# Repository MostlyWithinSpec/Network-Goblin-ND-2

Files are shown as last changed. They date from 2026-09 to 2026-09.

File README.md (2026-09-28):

# Network Goblin ND-2

**A Linux-powered handheld network multitool with real cable diagnostics.**

ND-2 is the bigger sibling of the [ND-1](#the-network-goblin-family) pocket cable tester. It's a custom carrier board for the Raspberry Pi Compute Module 5 with:

- a **dedicated test port** that can find opens, shorts and distance-to-fault on each pair (PHY-based TDR),
- a second gigabit port for uplink, capture and inline tapping,
- a touchscreen, battery power, 2x USB-A and HDMI out,
- a normal Linux distro underneath, so tcpdump, Wireshark, iperf3, nmap and friends just work.

Everything here, hardware and software, is open source under the MIT license.

> **Status: early hardware.** The first board, the **TDR proof dongle**, is at the fab. The full ND-2 carrier is still at the spec stage. Nothing here has been tested on real hardware yet.

---

## What's in this repo

| Path | What it is |
|---|---|
| [`docs/spec.md`](docs/spec.md) | Full ND-2 hardware spec (draft): architecture, part choices, power, BOM, risks |
| [`docs/roadmap.md`](docs/roadmap.md) | Where the project is going and in what order |
| [`docs/bring-up.md`](docs/bring-up.md) | Step-by-step first power-on and test plan for the TDR dongle |
| [`docs/ordering-jlcpcb.md`](docs/ordering-jlcpcb.md) | Exact JLCPCB settings used to order the dongle, and how to keep the cost down |
| [`hardware/tdr-dongle/`](hardware/tdr-dongle/) | **Rev A TDR proof dongle**: KiCad project, fab files, BOM, pick-and-place |
| [`hardware/nd2-carrier/`](hardware/nd2-carrier/) | The full CM5 carrier board (not started yet) |
| [`software/cabletest/`](software/cabletest/) | `nd2-cabletest`: a friendly wrapper around the Linux cable-test tools |

## The TDR proof dongle (Rev A)

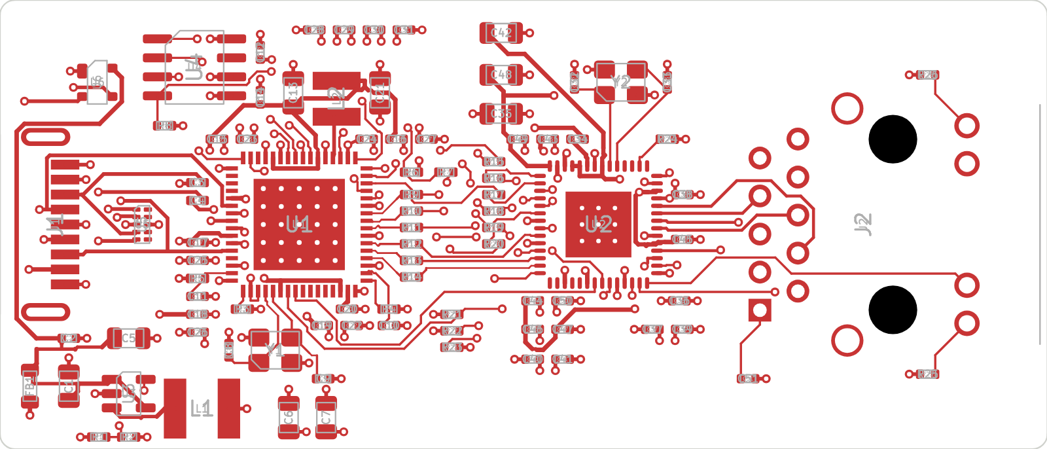
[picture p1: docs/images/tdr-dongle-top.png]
TDR dongle, top copper


A 70 x 30 mm USB 3 to gigabit Ethernet dongle that is **just the ND-2 test-port circuit**:

- **Microchip LAN7801**: USB 3 to RGMII MAC (`lan78xx` driver, mainline Linux)
- **Marvell 88E1512**: gigabit PHY with Virtual Cable Tester / TDR (`marvell` PHY driver, mainline Linux)
- **HanRun HR911130C**: 1G RJ45 magjack with LEDs
- 4-layer, 1.6 mm, all SMD parts on the top side, assembled by JLCPCB

It exists to prove that `ethtool --cable-test` works on this chip combo before building the full carrier. If it works, it's also useful by itself: **plug it into any Pi 5 or Linux laptop and you have a TDR cable tester.**

See [`hardware/tdr-dongle/README.md`](hardware/tdr-dongle/README.md) for the design details and fab files.

## Quick try (once you have a dongle)

```bash
# On a Pi 5 or any Linux machine with ethtool 5.8+ and a recent kernel
lsusb | grep 0424:7801             # the LAN7801 should show up
ip link                            # find the new interface, e.g. eth1
sudo ethtool --cable-test eth1     # per-pair OK / open / short + fault distance

# or the friendlier wrapper from this repo
sudo python3 software/cabletest/nd2-cabletest.py eth1
```

Unplug the far end of the cable first. TDR results are unreliable while there's an active link partner.

## The Network Goblin family

| Device | What it is |
|---|---|
| **ND-1** | Cheap, instant-on pocket cable tester. ESP32 + LAN8742A, 3.5" LCD. |
| **ND-2** | This repo. Linux handheld multitool on CM5, with a TDR test port. |
| **TDR dongle** | The ND-2 test port on its own, as a USB 3 dongle for any Linux box. |

## Contributing

Issues and pull requests are welcome, whether it's hardware review, bring-up results or software. See [CONTRIBUTING.md](CONTRIBUTING.md). Hardware bring-up reports on real boards are especially useful right now.

## License

[MIT](LICENSE), covering both hardware and software. Build it, fork it, sell it; a credit back to the project is appreciated.

**Not certified:** ND-2 isn't FCC/CE certified and isn't a TIA/ISO cable certifier. It tells you whether a cable is healthy enough, not whether it passes a formal certification test.

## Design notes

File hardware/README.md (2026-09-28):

# Hardware

| Board | Status | Folder |
|---|---|---|
| TDR proof dongle, Rev A | Ordered (JLCPCB, Sept 2026) | [`tdr-dongle/`](tdr-dongle/) |
| ND-2 CM5 carrier | Spec only | [`nd2-carrier/`](nd2-carrier/) |

All boards use **KiCad 10**. Each board folder is a self-contained KiCad project with its own symbol and footprint libraries.

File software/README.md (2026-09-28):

# ND-2 software

| Folder | What it is | Status |
|---|---|---|
| [`cabletest/`](cabletest/) | `nd2-cabletest.py`: per-pair cable test summary using `ethtool --cable-test` | Written, waiting for hardware |
| *(planned)* `eeprom/` | LAN7801 EEPROM image + script (MAC address, RGMII config) | After bring-up |
| *(planned)* `gui/` | Touch UI for the ND-2 handheld (LVGL on Linux DRM) | Stage 4 |

## nd2-cabletest

```bash
sudo apt install ethtool
sudo python3 software/cabletest/nd2-cabletest.py eth1
```

Example output (illustrative):

```
Cable test on eth1

Pair  Pins            Result                    Fault at
A     1-2 (orange)    OPEN                      12.4 m
B     3-6 (green)     OPEN                      12.6 m
C     4-5 (blue)      OPEN                      12.3 m
D     7-8 (brown)     OPEN                      12.5 m

All pairs open at about 12.5 m: that's probably the cable length (far end unplugged), not a fault.
```

It works with any Linux NIC whose PHY driver supports cable test, not just the ND-2 dongle.

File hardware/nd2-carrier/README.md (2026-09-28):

# ND-2 CM5 carrier board

Not started. It will begin once the TDR dongle proves the LAN7801 + 88E1512 test-port circuit ([roadmap](../../docs/roadmap.md)).

The design target is in [`docs/spec.md`](../../docs/spec.md): CM5 carrier, TDR test port (copied from the dongle), CM5 native uplink port, USB 3 hub + 2x USB-A, M.2 2230, DSI touchscreen, HDMI, USB-C PD input, 2S Li-ion with BQ25798 charger and fuel gauge.

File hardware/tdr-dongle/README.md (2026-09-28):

# ND-2 TDR Proof Dongle — Rev A

Top copper

A small USB 3 → Gigabit Ethernet dongle that is just the ND-2 test-port circuit:
**Microchip LAN7801** (USB 3 to RGMII MAC) + **Marvell 88E1512** (GbE PHY with VCT/TDR) + HanRun 1G magjack.
Plug it into a Pi 5 / CM5 IO board and prove `ethtool --cable-test` / `--cable-test-tdr` before building the CM5 carrier.

**Status:** ERC and DRC clean, schematic/PCB parity clean, ordered from JLCPCB in Sept 2026. **Not yet tested on real hardware.** Bring-up plan: [docs/bring-up.md](../../docs/bring-up.md).

## Files

| File | What it is |
| --- | --- |
| `tdr-dongle.kicad_sch` | Schematic (KiCad 10, one A2 sheet, label-based wiring) |
| `ND2.kicad_sym` + `sym-lib-table` | Project symbols: `ND2:LAN7801`, `ND2:88E1512`, `ND2:HR911130C` |
| `ND2.pretty` + `fp-lib-table` | Project footprints (from LCSC/EasyEDA, cleaned up — see below) |
| `bom_jlcpcb.csv` | Grouped BOM in JLCPCB format (Comment, Designator, Footprint, LCSC Part #) |
| `bom.csv` | One line per part with MPN + LCSC |
| `netlist_report.txt` | Every net and the pins on it |
| `tdr-dongle.kicad_pcb` | PCB: 70 x 30 mm, 4-layer |
| `tdr-dongle.kicad_pro` | KiCad project (design rules, net classes) |
| `tdr-dongle.net` | KiCad netlist export |
| `fab/` | Fabrication package: Gerber zip, JLC BOM + CPL, layer PDF, schematic PDF, STEP, renders |
| `scripts/` | Python scripts that generated the schematic and PCB (see [scripts/README.md](scripts/README.md)) |

## Parts (LCSC, checked 2026-09-25)

| Ref | Part | LCSC | Footprint | Notes |
| --- | --- | --- | --- | --- |
| U1 | LAN7801-I/9JX | C633491 | ND2:LAN7801_QFN-64-1EP_9x9mm_P0.5mm_EP6.1mm | Only ~13 in stock at LCSC |
| U2 | 88E1512-A0-NNP2C000 | C845579 | ND2:88E1512_QFN-56-1EP_8x8mm_P0.5mm_EP4.4mm | Only ~13 in stock at LCSC |
| U3 | TLV62569DBVR | C141836 | SOT-23-5 | 3V3 buck |
| U4 | 93AA66/SN | C615340 | SOIC-8 | ORG pin (6) tied to GND = 512 x 8 |
| U5 | TPD4EUSB30DQAR | C90627 | USON-10 | USB 3 ESD |
| U6 | PRTR5V0U2X,215 | C12333 | SOT-143 | USB 2 ESD |
| J1 | HC-USB3.0-C26 (USB 3 Type-A plug, SMD) | C7501854 | ND2:USB3_A_Plug_HongCheng_HC-USB3.0-C26 | Flash-drive style plug at the board edge |
| J2 | HanRun HR911130C (1G magjack, 2 LEDs) | C50933 | ND2:RJ45_HanRun_HR911130C_Horizontal | Replaces the Pulse JK0654219NL (0 stock) |
| Y1, Y2 | X322525MOB4SI 25 MHz, CL 12 pF | C9006 | Crystal_SMD_3225-4Pin | Load caps changed to 15 pF |
| L1 | SMNR4020-2.2UH (3.4 A) | C135262 | ND2:L_4.0x4.0mm_SMNR4020 | Buck inductor |
| L2 | SMNR3015-3R3MT (1.32 A) | C135239 | ND2:L_3.0x3.0mm_SMNR3015 | LAN7801 1V2 switcher |
| FB1 | MPZ2012S601AT000 (600 Ω, 2 A) | C21519 | L_0805 | VBUS filter |
| Caps | 100 nF C1525 · 1 µF C52923 · 220 nF C16772 · 15 pF C1548 (0402) · 10 µF C15850 · 22 µF C45783 (0805) | | | |
| Resistors (0402, UNI-ROYAL) | 22R C25092 · 330R C25104 · 0R C17168 · 1.5k C25867 · 2k C4109 · 4.99k C25903 · 10k C25744 · 12k C25752 · 100k C25741 · 453k C27009 | | | |

## Changes from the first draft

- **Magjack → HanRun HR911130C.** The Pulse part had no stock. The HR911130C has one **common** center tap (pin 1 → one 100 nF to GND) and an internal Bob-Smith termination on pin 10 (tied to GND). LEDs: 11/12 green (anode/cathode), 14/13 yellow (anode/cathode).
- **EEPROM → 93AA66/SN** (the x8-only 93AA66A wasn't stocked in SOIC). ORG pin tied low selects 512 x 8.
- **Crystals → 12 pF load** (YXC, 70k in stock); load caps now 15 pF.
- **Real footprints** for U1, U2, J1, J2, L1, L2, taken from LCSC/EasyEDA and fixed up:
  - LAN7801 pads resized to Microchip's recommended land pattern (0.30 × 0.85 mm pads, 6.1 mm exposed pad), plus 5 × 5 thermal vias (0.33 mm) and a split paste stencil.
  - 88E1512 exposed pad 4.4 mm (datasheet D2/E2 = 4.37 mm), 3 × 3 thermal vias numbered to the pad, split paste.
  - HR911130C / USB plug pads renumbered to match the symbols; the RJ45 plastic posts made non-plated.

## Known issues and Rev B ideas

1. **Stock on U1 / U2** — about 13 of each at LCSC right now. Enough for a few prototypes; for more, JLCPCB global sourcing or Mouser/Digi-Key.
2. **J1 plug** hangs over the board edge and was left off the JLC assembly (hand-soldered). Rev B: USB-C receptacle + cable.
3. RGMII series resistors (22 Ω) are a starting value; tune after the first boards.
4. Optional: low-capacitance TVS on the MDI pairs, test points on RGMII/MDIO.

## Bring-up plan

1. Power only: check +5V, +3V3, LAN_1V2, LAN_2V5, PHY_1V8, PHY_1V0.
2. Plug into a Pi 5: `lsusb` should show 0424:7801. Program the EEPROM with MAC + HW_CFG (hybrid RGMII delay, CLK125_EN).
3. `dmesg` should show lan78xx attaching the Marvell 88E1510-family PHY at address 0.
4. Link test: clean 1 Gb/s link, iperf3, watch for CRC errors (wrong RGMII delay).
5. TDR: `ethtool --cable-test ethX` and `ethtool --cable-test-tdr ethX` on known cables (open, short, known lengths).

## PCB and fab package (Rev A)

- Board: 70 x 30 mm, 4-layer 1.6 mm (JLC04161H-7628). F.Cu signals, In1 = GND plane, In2 = +3V3 plane, B.Cu signals.
- Rules: 0.1 mm min track (Freerouting necks to ~0.11 at the QFN pins), 0.127 mm clearance, 0.6/0.3 mm vias.
- Routing: plane fan-out by script (scripts/fanout.py), the rest by Freerouting 2.4.1, and 2 nets fixed by hand (scripts/fix_last2.py).
- DRC: 0 errors, 0 warnings, 0 unconnected, schematic parity clean (KiCad 10.0.5).

`fab/` holds:
- `tdr-dongle_gerbers_JLC.zip`: Gerbers + Excellon drills. Upload this to JLCPCB and pick 4 layers, 1.6 mm, JLC04161H-7628.
- `tdr-dongle_BOM_JLC.csv`: the BOM (R7 is DNP and left out).
- `tdr-dongle_CPL_JLC.csv`: pick and place (89 parts, all top side, origin at the board's lower-left corner).
- `tdr-dongle_layers.pdf`, `tdr-dongle_schematic.pdf`, `tdr-dongle.step`, and top/bottom renders for review.

Caveats:
- USB3 and MDI pairs were autorouted. They are **not** length-matched or impedance-controlled. That is fine for a proof dongle but not final.
- Check part rotations in JLC's CPL preview, especially J1, J2, U1, U2 and the crystals.
- LAN7801 and 88E1512 LCSC stock was low (~13 each) when checked.

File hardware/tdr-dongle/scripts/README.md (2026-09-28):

# Generation scripts

The Rev A schematic and PCB were generated by script, then checked in KiCad. These scripts are kept for reference and for building later revisions the same way.

> **Heads-up:** most scripts have a placeholder Windows project path hard-coded (`C:\path\to\ND2\tdr-dongle`) and expect KiCad 10's bundled Python (`C:\Program Files\KiCad\10.0\bin\python.exe`). Change the `P = ...` line at the top before running them.

| Script | Step | What it does |
|---|---|---|
| `gen_dongle.py` | 1 | Writes `tdr-dongle.kicad_sch` (label-based schematic). **Overwrites the schematic.** |
| `fix_courtyards.py`, `fix_usb_edge.py`, `fix_rj45_silk.py` | 2 | One-off clean-ups of the EasyEDA-imported footprints in `ND2.pretty` |
| `build_pcb.py` | 3 | Builds `tdr-dongle.kicad_pcb` from `tdr-dongle.net`: outline, stackup, rules, net classes, placement, planes. **Overwrites the PCB.** |
| `fanout.py` | 4 | Adds locked stub + via fan-outs from every GND / +3V3 pad to the inner planes |
| `route_start.py` / `route_finish.py` | 5 | Exports Specctra DSN, runs Freerouting 2.4.1 (needs Java 25), imports the SES |
| `fix_last2.py` | 6 | Hand-routes the two connections Freerouting left open (LAN_SW, C24 +3V3) |
| `drc_brief.py`, `drc_summary.py` | check | Runs `kicad-cli pcb drc` with schematic parity and prints a summary |
| `render_layers.py`, `render_zoom.py` | check | SVG exports for visual review |
| `export_fab.py` | 7 | Writes the fab package (Gerbers + drill zip, JLC CPL, BOM, PDFs, STEP) |
| `export_dsn.py`, `run_seq.py` | helpers | DSN export on its own; run several scripts one after another |

Because the PCB was routed by hand after these scripts ran, **re-running `build_pcb.py` will throw away the routing.** Edit the board in KiCad from here on.

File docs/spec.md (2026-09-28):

# Network Goblin ND-2 — Hardware Spec (Draft)

*Draft, 2026-09-25. Mirrors the working spec doc; this copy lives with the hardware so changes can go through pull requests.*

## 1. Overview

ND-2 is the Linux-powered member of the Network Goblin family: a handheld network multitool built as a custom carrier board for the Raspberry Pi Compute Module 5. ND-1 stays the cheap, instant-on pocket cable tester (ESP32 + LAN8742A). ND-2 is the one you bring when you need to capture, measure, tap and poke at a live network.

**Goals**

- Cable diagnostics on a dedicated test port: per-pair open/short detection, distance to fault and cable length (PHY TDR).
- Two gigabit Ethernet ports: one test port with TDR, one general-purpose port.
- Packet capture (tcpdump / Wireshark / tshark), iperf3 throughput testing, inline tap (bridge), port-mirror target.
- Security-oriented tooling (nmap, scapy, Kismet-type tools, etc.) on a standard Linux distro.
- Handheld and battery powered, with a small capacitive touchscreen running a custom GUI.
- 2x USB-A, one HDMI output for occasional desk use.
- Fully open source (hardware + software), kept at a sensible cost so the community can build it.

**Non-goals**

- TIA/ISO cable **certification** (NEXT, return loss, insertion loss up to 250–500 MHz). PHY-based TDR can't do that, and it's not the point. ND-2 checks that a line is in spec *enough*, or mostly in spec.
- A fail-open passive tap in Rev A (inline tap is an active Linux bridge; see Risks).
- Wiremap / split-pair detection without a remote unit (possible future accessory).

## 2. System architecture

```mermaid
flowchart LR
  subgraph TEST["Test path (TDR)"]
    RJT["Test port RJ45<br/>magjack"] --- PHY["Marvell 88E1512<br/>GbE PHY + VCT/TDR"]
    PHY -- "RGMII + MDIO" --- LAN["LAN7801<br/>USB 3 to RGMII MAC"]
  end
  LAN -- "USB 3" --- CM5["Raspberry Pi CM5<br/>BCM2712 · BCM54210PE PHY"]
  CM5 -- "MDI (on-module PHY)" --- RJU["Uplink RJ45"]
  CM5 -- "USB 3" --- HUB["USB 3 hub"] --- USBA["2x USB-A"]
  CM5 -- "PCIe x1" --- M2["M.2 2230<br/>NVMe or Wi-Fi"]
  CM5 -- "DSI + I2C" --- LCD["Touchscreen"]
  CM5 -- "HDMI0" --- HDMI["HDMI out"]
  USBC["USB-C in<br/>PD 9-15 V"] --> CHG["PD sink + BQ25798<br/>2S charger"]
  CHG --- BAT["2S Li-ion + fuel gauge"]
  CHG -- "VSYS" --> BUCK["5 V / 5 A buck<br/>+ 3.3 V rail"] --> CM5
```
*ND-2 system architecture (CM5 carrier). The top group is the TDR test path.*

The CM5's two USB 3 ports do the heavy lifting: one feeds a LAN7801 + Marvell 88E1512 to make the TDR-capable test port, the other feeds a small hub for the two USB-A ports. The CM5's own gigabit PHY becomes the uplink port, which leaves the single PCIe lane free for an M.2 slot.

| Interface | Source on CM5 | Used for |
|---|---|---|
| eth0 (native) | On-module BCM54210PE PHY | Uplink / capture / mirror target / iperf |
| eth1 (test) | USB 3 port 0 → LAN7801 → Marvell 88E1512 | Cable diagnostics, link tests, second leg of inline tap |
| USB-A x2 | USB 3 port 1 → 4-port USB 3 hub | Adapters, Wi-Fi dongles, storage, keyboard |
| M.2 2230 (M- or E-key, TBD) | PCIe Gen2/3 x1 | NVMe for captures or a monitor-mode Wi-Fi card |
| Touchscreen | MIPI DSI (4-lane) + I2C | Primary UI |
| HDMI | HDMI0 | Occasional desktop use |
| USB-C | Power input (+ optional USB 2 gadget/console) | Charging, data link to a laptop |

## 3. Compute module

**Choice: Raspberry Pi Compute Module 5.** From the [CM5 datasheet](https://datasheets.raspberrypi.com/cm5/cm5-datasheet.pdf):

- 2x USB 3.0 (5 Gb/s, usable at the same time) + 1x USB 2.0
- 1x PCIe Gen 2 x1 (Gen 3 possible but unsupported)
- On-module Broadcom BCM54210PE gigabit PHY with IEEE 1588 PTP
- 2x HDMI 2.0, 2x 4-lane MIPI (DSI or CSI)
- 5 V input (4.75–5.25 V), up to 5 A budget with USB loads; ~0.4 A idle, ~0.9 A typical
- PWR_BUT (pin 92), PMIC_EN (pin 99), RTC VBAT (pin 76), Fan_PWM / Fan_Tacho (pins 19/16)

**Why not CM4:** the CM4 only has USB 2.0 (480 Mb/s). A USB-attached second NIC would be stuck well below gigabit, and the only way around that is the single PCIe lane, which is then gone for USB 3 or storage. PCIe NICs that work well on the Pi (Realtek RTL8111, Intel i210/i225) have no cable-test support in Linux. The CM5's native USB 3 removes the whole problem.

**Variants to support:**

| Variant | Notes |
|---|---|
| CM5 Lite (no eMMC), 2–4 GB | Cheapest build. Boots from microSD slot on the carrier (or NVMe if M.2 is M-key). Recommended community default. |
| CM5 with eMMC, 4–8 GB | Faster, more robust boot. Heavier Wireshark/Kismet use benefits from 4 GB+. |
| Wireless vs non-wireless | Either works. On-module Wi-Fi is fine for management; monitor-mode security work should use a USB or M.2 adapter anyway. Needs antenna keep-out (10 mm) or U.FL if the case is metal. |

The carrier keeps the standard 2x 100-pin Hirose DF40 footprint. A CM4 would physically fit but would lose USB 3 (so the test port and USB-A ports fall back to USB 2 speeds); treat that as unsupported rather than a design target.

## 4. Networking

### 4.1 Test port (eth1): LAN7801 + Marvell 88E1512

- **MAC bridge:** Microchip LAN7801, 64-pin SQFN. USB 3.0 SuperSpeed + USB 2.0 upstream to CM5 USB3 port 0 (0.1 µF AC-coupling caps on SS TX). Linux driver: `lan78xx` (mainline, used on the Pi 3B+ already). The LAN7801 stays no matter which PHY sits behind it; it's what turns USB 3 into an Ethernet MAC.
  - 25 MHz crystal; REFCLK_25 output can clock the PHY (saves a second crystal).
  - Internal 2.5 V LDO and 1.2 V switcher (needs 3.3 µH + 22 µF).
  - VDDVARIO = 3.3 V or 1.8 V for the RGMII bank; match the PHY's VDDO.
  - 3-wire 93C66-type EEPROM for MAC address and config, including the MAC-side RGMII clock delays (not optional with the Marvell PHY).
  - ~10 Ω series resistors on RGMII lines, 1.5 k pull-up on MDIO.
- **PHY: Marvell 88E1512** (56-pin QFN 8x8, LCSC C845579, ~$11 at qty 1 vs ~$3.70 for the KSZ9131RNX). RGMII to the LAN7801, MDI to the RJ45. Linux driver: `marvell`, which supports both `--cable-test` (per-pair status + fault distance) and `--cable-test-tdr` (raw amplitude vs. distance for a real TDR trace).
  - Runs from a single 3.3 V supply using its internal switching regulator; VDDO selectable 1.8/2.5/3.3 V.
  - RGMII delays must be added in exactly one place. Plan: the LAN7801 adds TX/RX clock delays (set in its EEPROM) and the PHY runs plain RGMII. Others have paired non-Microchip PHYs with the LAN7801 this way. Fallback: have the PHY insert the delays instead (register-configured; the Marvell driver does this from the interface mode) through a small driver/overlay tweak.
  - Reference clock from LAN7801 REFCLK_25; keep a 25 MHz crystal footprint as a DNP backup.
  - Docs: Marvell's full register manual is behind their customer portal, but a public product datasheet exists and the mainline Linux driver already implements the VCT/TDR sequences, so nothing ND-2 needs is locked away.
  - Fallback part: KSZ9131RNX (Microchip's own LAN7801 pairing, simpler bring-up, no raw TDR). Not footprint-compatible, so the choice is made per board revision.
- **Connector:** RJ45 magjack with integrated magnetics and LEDs (same family as ND-1, e.g. HanRun HR911130 class 1G part). TVS array on MDI pairs (e.g. low-capacitance 4-line array), shield to chassis ground through RC.

### 4.2 Uplink port (eth0): CM5 native

- CM5's BCM54210PE MDI pairs route straight to a second 1G magjack. LEDs from CM5 Ethernet_nLED pins.
- This is the "fast" port: on-SoC MAC, PTP-capable, lowest latency. Use it for iperf, captures and as the mirror target.

### 4.3 Operating modes (software)

| Mode | Ports | Notes |
|---|---|---|
| Cable test | eth1 | Link down, run TDR, show per-pair result + distance |
| Link / port check | eth1 or eth0 | Negotiated speed/duplex, PoE present (future), LLDP/CDP neighbor, VLAN, DHCP, gateway ping, DNS |
| Throughput | eth0 (or both) | iperf3 client/server; port-to-port loopback test through a switch |
| Capture | eth0 / eth1 | tcpdump/tshark to NVMe or USB; live summary on screen; export pcap |
| Port-mirror target | eth0 | Promiscuous capture from a switch SPAN port |
| Inline tap | eth0 + eth1 bridged | Linux bridge; capture on br0. Active tap: link breaks if ND-2 powers off |
| Security tools | any | nmap, scapy, arp-scan, responder-type tools, Kismet with USB/M.2 Wi-Fi |

Throughput note: USB 3 gives the LAN7801 plenty of headroom for 1 Gb/s line rate, but bridging both ports at full duplex line rate will be CPU-bound. Expect it to be fine for typical tap/capture use; benchmark in bring-up.

## 5. Cable diagnostics

**What the 88E1512 Virtual Cable Tester (VCT) gives you** through the standard Linux ethtool netlink cable-test API (driver already in mainline, no NDA needed):

- Per pair (A–D): OK, open, short within pair, short to another pair
- Distance to the fault; Marvell specs fault location to within about 1 m
- **Raw TDR trace:** `--cable-test-tdr` returns reflection amplitude vs. distance for each pair, with configurable start/stop/step. The GUI can plot a real TDR view that shows bad connectors, kinks and mismatched patch cords, not just open/short.
- **Cable length:** leave the far end unplugged; each pair shows an open at the cable's end, and that distance is the length. The GUI should prompt for this ("Unplug far end for length").
- **With link up at 1 Gb/s:** the PHY's DSP also estimates cable length and reports pair swaps, polarity and pair skew in vendor registers. ethtool doesn't expose these, but a small MDIO helper can read them for the link-check screen.

**How the test runs:** the driver drops the link while testing. Results are cleanest with the far end unplugged or its device powered off; the GUI should warn when a link partner is detected.

**What it can't do**

- Certification-grade measurements (NEXT, return loss, insertion loss vs. frequency)
- Split-pair detection and full wiremap without a remote identifier at the far end
- Length through ethtool on a cable plugged into a live switch (pairs read OK with no distance; use the DSP length estimate instead)

**Filling the gaps cheaply**

- **Link qualification:** force 1000BASE-T, run a 30 s iperf3 or packet-generator test against a known endpoint, read PHY error counters and link flaps. "Passes gigabit cleanly" is the practical in-spec check.
- **Wiremap remote (future accessory):** a tiny passive or MCU-based terminator with distinct resistor/diode signatures per pair, like the remotes that come with cheap wiremap testers. Could be shared with ND-1.

**Software path:** `ethtool --cable-test eth1` for the pass/fail summary and `ethtool --cable-test-tdr eth1` for the trace. The GUI calls the same netlink API directly (pyroute2 or libmnl).

## 6. USB, storage and expansion

- **USB 3 hub:** VIA VL817 (4-port USB 3.0 hub, widely stocked, cheap) on CM5 USB3 port 1. Two downstream ports go to USB-A; the spare two are left for a future internal module (e.g. an internal Wi-Fi or SDR daughterboard).
- **2x USB-A:** vertical or right-angle USB 3 receptacles. Each behind a current-limited load switch (~1 A each, e.g. TPS2553-class) so a shorted dongle can't brown out the CM5. ESD protection on D+/D− and SS pairs.
- **USB-C:** power input (see Power). Optionally route CM5's USB 2.0 port here too for gadget mode (serial console / USB-Ethernet to a laptop) with a mux or simple jumper; verify CM5 device-mode support on this port during bring-up.
- **microSD:** required for CM5 Lite (SDIO on the CM5 connector). Push-push socket, card-detect to a GPIO.
- **M.2 slot (PCIe x1):** recommend **M-key 2230/2242 for NVMe** as the default. Captures go to fast storage, and the Pi 5 ecosystem supports NVMe boot. Monitor-mode Wi-Fi is better served by USB adapters, which have more mature driver support. Include a PCIe CLKREQ/reset per CM5 IO board reference, 3.3 V at 2–3 A from its own buck.
- **HDMI:** one micro- or mini-HDMI (full-size if the case allows) on HDMI0, with an HDMI ESD/level companion (TPD12S016-class) handling DDC level shifting, HPD and the 5 V current limit.
- **Fan header:** 2-pin or 4-pin to CM5 Fan_PWM/Fan_Tacho. A small blower is likely needed in an enclosed handheld during long captures.

## 7. Display, controls and indicators

**Display:** MIPI DSI touchscreen on one of the CM5's 4-lane MIPI ports, 22-pin 0.5 mm FPC (the CM-style DSI connector; 2-lane panels also fit). Touch controller on the I2C lines in the same cable, backlight/touch power from a separate 5 V / 3.3 V pin header.

| Option | Size / res | Why |
|---|---|---|
| Raspberry Pi Touch Display 2 (5") | 720x1280 | Official driver, zero bring-up work, easy for builders to buy |
| Waveshare 4.3" or 5" DSI LCD | 800x480 | Cheaper, smaller, Pi-compatible overlays exist |
| Bare DSI panel + custom FPC | 4–5" | Best fit for a handheld case later; more driver work |

Recommendation: design around the official 5" panel for Rev A (known-good), keep the connector generic so cheaper panels work.

**Controls**

- Power button to CM5 PWR_BUT (short press = on / clean shutdown, hold 5 s = force off)
- Hard power switch in the battery path for storage/shipping
- 3–4 GPIO buttons: Back, Home, and a dedicated **Test** button that runs a cable test on eth1 without touching the screen

**Indicators and extras**

- Charge status LED from the charger; one addressable RGB status LED (test pass/fail, capture running)
- Magjack LEDs on both ports
- RTC: rechargeable ML2032-type cell or supercap to CM5 VBAT so capture timestamps survive battery swaps
- Debug UART header (3-pin) and a Qwiic/STEMMA I2C connector for add-ons (e.g. a PoE detector board)

## 8. Power system

**Why 2S, not 1S:** peak system load is 15–20 W with USB devices attached. From a single 3.7 V cell that's 5+ A through a boost converter, which means hot inductors, big voltage droop and early brown-outs. A 2S pack (6.0–8.4 V) lets a simple buck make 5 V efficiently.

**Chain:** USB-C → PD sink → buck-boost charger with power path → VSYS (pack voltage) → 5 V / 5 A buck → CM5 + peripherals; a second buck from VSYS for 3.3 V (M.2, LAN7801, PHY).

| Block | Part (proposed) | Notes |
|---|---|---|
| PD sink | TI TPS25730 | Standalone, strap-configured (no firmware), integrated power switches, LCSC stocked. Request 9–15 V; falls back to 5 V on dumb chargers |
| Charger / power path | TI BQ25798 | I2C, 1–4 cell, 5 A buck-boost, 3.6–24 V input. Buck-boost means even a plain 5 V USB charger can charge the 2S pack. Runs the system from USB when plugged in |
| Battery | 2S1P Li-ion, 21700 or 18650 (with PCM) | 2x 21700 5000 mAh ≈ 36 Wh. Use a pack with built-in protection + balancing, or add a 2S protector/balancer (e.g. BQ29209-class) |
| Fuel gauge | TI BQ34Z100-G1 | Multi-cell gauge with real %-remaining; I2C to CM5. Low-battery interrupt triggers clean shutdown |
| 5 V rail | 5 V / 5–6 A sync buck (e.g. TPS56637-class, 4.5–28 V in) | Feeds CM5 (via its 5 V pins), USB hub, USB-A load switches, display |
| 3.3 V rail | 3 A sync buck from VSYS | M.2, LAN7801, 88E1512 (the CM5's own 3.3 V output is only ~600 mA total, not enough) |
| On/off | CM5 PWR_BUT + PMIC_EN, hard switch in pack line | Gauge/charger stays alive for charging while the system is off |

**Power budget (estimates, to confirm on the bench)**

| Load | Typical | Peak |
|---|---|---|
| CM5 (idle ~2 W, working ~4.5 W) | 4.5 W | 10 W |
| LAN7801 + 88E1512 at 1 Gb/s | 1.0 W | 1.5 W |
| 5" DSI display + backlight | 1.5 W | 2.0 W |
| USB hub | 0.5 W | 0.8 W |
| NVMe (idle / writing) | 0.5 W | 3.0 W |
| USB-A devices (e.g. Wi-Fi adapter) | 1.5 W | 9.0 W (2x 0.9 A) |
| **Total** | **~9.5 W** | **~26 W** |

The worst case assumes both USB-A ports at full current while the CPU and NVMe are maxed out, which is rare; firmware can cap USB-A current if needed. Expected runtime on a 36 Wh pack at ~9.5 W average with ~88% conversion efficiency: **roughly 3–3.5 hours** of active use.

## 9. Preliminary BOM (key parts)

Passives, ESD parts and connectors beyond the main ones are left out. Part numbers are starting points; check LCSC/JLC stock before locking the schematic.

| Function | Part | Qty | Package |
|---|---|---|---|
| Compute | Raspberry Pi CM5 (Lite 4 GB suggested default) | 1 | Module |
| CM connectors | Hirose DF40C-100DS-0.4V (carrier side) | 2 | 100-pin |
| USB3 → RGMII MAC | Microchip LAN7801 | 1 | 64-SQFN |
| TDR PHY | Marvell 88E1512-A0-NNP2C000 (fallback: KSZ9131RNX) | 1 | 56-QFN 8x8 |
| MAC config EEPROM | 93C66-type 3-wire (required: MAC + RGMII delay config) | 1 | SOT-23/SOIC |
| 25 MHz crystal | For LAN7801 (PHY clocked from REFCLK_25) | 1 | 3225 |
| RJ45 magjack, 1G, LEDs | HanRun HR911130-class | 2 | THT |
| USB 3 hub | VIA VL817 | 1 | QFN-76 |
| USB-A receptacles (USB 3) | Generic | 2 | THT |
| USB-A load switches | TPS2553-class | 2 | SOT-23-6 |
| HDMI companion | TPD12S016-class | 1 | QFN |
| micro/mini HDMI connector | Generic | 1 | SMD |
| M.2 M-key socket + standoff | Generic | 1 | SMD |
| microSD socket | Push-push | 1 | SMD |
| DSI FPC connector | 22-pin 0.5 mm | 1 | SMD |
| USB-C receptacle (16-pin) | Generic | 1 | SMD |
| PD sink | TI TPS25730 | 1 | QFN |
| Charger | TI BQ25798 | 1 | QFN-29 |
| Fuel gauge | TI BQ34Z100-G1 | 1 | TSSOP-14 |
| 5 V buck | TPS56637-class + inductor | 1 | SOT/QFN |
| 3.3 V buck | 3 A sync buck + inductor | 1 | SOT |
| RTC cell | ML2032 rechargeable + holder | 1 | THT/SMD |
| Battery | 2S 21700 pack with PCM + JST-XH balance lead | 1 | — |

## 10. Cost strategy for open-source adoption

The CM5 is the single most expensive part, so most savings come from letting builders pick their own module and leaving optional parts unpopulated.

- **The carrier doesn't include the module.** Builders choose any CM5: a Lite 2–4 GB for a budget build, eMMC/8 GB for heavy capture work. Document which features need which RAM size.
- **Optional-population zones:** M.2 slot, HDMI, hub ports 3–4, fan header and fuel gauge can be left off without breaking anything. Mark them DNP-friendly in the BOM.
- **Buy-don't-build for the screen and battery:** off-the-shelf DSI panel and a standard 2S pack keep the carrier simple and JLC-assemblable.
- **Keep all fine-pitch parts on one side** so JLCPCB standard assembly can do the whole board; hand-solder only THT (RJ45, USB-A, battery connector).
- **Public documentation first** (Microchip, TI, VIA). The one partial exception is the Marvell PHY: its full register manual is gated, but everything ND-2 uses is already in the open-source Linux driver, so forks aren't blocked.
- **Firmware reuse:** the ND-1 LVGL UI concepts can carry over. LVGL runs on Linux framebuffer/DRM, so screens, icons and the goblin style can be shared between ND-1 and ND-2.

## 11. Risks, open questions and bring-up plan

**Risks**

| Risk | Impact | Mitigation |
|---|---|---|
| lan78xx + external PHY RGMII delay setup | Test port doesn't link or has CRC errors | Set delays in one place (LAN7801 EEPROM), keep PHY-side delay as a fallback, prove it on a small LAN7801 + 88E1512 test board before the full carrier |
| TDR less reliable with a live link partner | Wrong or "unknown" results | GUI detects a link partner and asks the user to unplug the far end |
| High-speed routing (USB 3, PCIe, HDMI, DSI, MDI) | Signal integrity problems | 4- or 6-layer stackup with controlled impedance (90 Ω USB/PCIe, 100 Ω MIPI/HDMI/MDI); copy the CM5 IO board's routing rules |
| Thermal in a closed handheld | CPU throttling during capture | Fan header, CM5 heatsink contact to case, measure early |
| 2S pack safety and shipping | Fire risk, hard to ship kits | Only protected packs; builder sources battery locally |
| Active tap fails closed | Inline link drops if ND-2 dies | Document it; consider a relay-based bypass in Rev B |

**Open questions**

- Test port PHY: decided on Marvell 88E1512 (raw TDR trace); KSZ9131RNX is the fallback.
- M.2 as M-key (NVMe) or E-key (Wi-Fi)?
- Screen size and orientation: 5" portrait-native panel used in landscape, or a 4.3" 800x480?
- Include PoE detection on the test port (voltage + class sensing) in Rev A or as an add-on?
- Case form factor: handheld "brick" like ND-1 scaled up, or tablet-style?

**Bring-up plan**

1. **TDR proof board:** a small USB 3 dongle PCB with just the test-port circuit (LAN7801 + 88E1512 + EEPROM + magjack). Plug it into a CM5 IO board or a Pi 5, get the link stable at 1 Gb/s (RGMII delays), then confirm `ethtool --cable-test` and `--cable-test-tdr` on Raspberry Pi OS. Cheap to iterate, and the schematic drops straight into the carrier.
1. **Rev A carrier:** full feature set, generous test points, 0 Ω jumpers on every rail so each block can be powered up alone.
1. **Power-on order:** power chain alone (no CM5) → add CM5 + boot from SD → USB hub → LAN7801/PHY → display → M.2 → battery-only runtime test.
1. **Validate:** cable test against known-length cables with opens/shorts built in, iperf3 at line rate on both ports, bridged tap throughput, thermal soak, battery runtime.

## Sources

- [Raspberry Pi CM5 datasheet](https://datasheets.raspberrypi.com/cm5/cm5-datasheet.pdf)
- [Marvell PHY TDR amplitude graph patch](https://patches.linaro.org/project/netdev/patch/20200524152747.745893-5-andrew@lunn.ch/)
- [88E1512-A0-NNP2C000 at LCSC](https://www.lcsc.com/product-detail/C845579.html)
- [88E1512 overview (single 3.3 V supply, VCT, RGMII delay modes)](https://www.utmel.com/components/88e1512-a0-nnp2c000-energy-efficient-ethernet-transceiver-features-pinout-and-datasheet?id=1366)
- [KSZ9131RNX at LCSC](https://www.lcsc.com/product-detail/C1849397.html)
- [KSZ9031/KSZ9131 cable test kernel patch](https://patchwork.kernel.org/project/netdevbpf/patch/20220406185020.301197-1-marex@denx.de/)
- [LAN7801 schematic checklist](https://www.microchip.com/content/dam/mchp/documents/OTH/ProductDocuments/SupportingCollateral/SchematicChecklistLAN7801SQFNRevA.pdf)
- [EVB-LAN7801-KSZ9031 user guide](https://ww1.microchip.com/downloads/en/DeviceDoc/500002605A.pdf)
- [lan78xx LAN7801 external PHY discussion](https://patchew.org/linux/20240611094233.865234-1-rengarajan.s@microchip.com/)
- [LAN7801 with a non-Microchip PHY, delays set in EEPROM](https://lkml.iu.edu/2602.2/00468.html)
- [TI BQ25798 datasheet](https://www.ti.com/lit/ds/symlink/bq25798.pdf)
- [TI TPS25730](https://www.ti.com/product/TPS25730)

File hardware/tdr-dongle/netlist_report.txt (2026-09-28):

ND-2 TDR dongle - generated net list (net: ref.pin(name) ...)

+3V3           L1.2(2)  C6.1()  C7.1()  R1.1()  U1.29(VBUS_DET)  U1.33(DUPLEX)  U1.50(VDD33A)  U1.64(VDD33_REG_IN)  U1.21(VDD_SW_IN)  U1.3(VDDVARIO)  U1.7(VDDVARIO)  U1.11(VDDVARIO)  U1.18(VDDVARIO)  U1.27(VDDVARIO)  U1.48(VDDVARIO)  U1.51(VDDVARIO)  R5.1()  U4.8(VCC)  C12.1()  R8.2()  C21.1()  C22.1()  C23.1()  C24.1()  C25.1()  C26.1()  C27.1()  C28.1()  C29.1()  C30.1()  C31.1()  R21.1()  R22.1()  U2.20(AVDD33)  U2.25(AVDD33)  U2.36(REG_IN)  U2.11(VDDO)  U2.49(VDDO)  U2.52(VDDO)  C35.1()  C36.1()  C37.1()  C38.1()  C39.1()  C40.1()  C41.1()  R25.1()  R26.1()
+5V            FB1.2()  C1.1()  C2.1()  U6.4(VCC)  U3.1(EN)  U3.4(VIN)  C5.1()
BUCK_FB        U3.5(FB)  R1.2()  R2.1()
BUCK_SW        U3.3(SW)  L1.1(1)
EE_CLK         U1.26(EECLK/GPIO3)  U4.2(SCLK)
EE_CS          U1.23(EECS/GPIO0)  U4.1(CS)
EE_DI          U1.25(EEDO/GPIO2)  U4.3(DI)
EE_DO          U1.24(EEDI/GPIO1)  U4.4(DO)  R8.1()
GND            J1.4(GND)  J1.7(DRAIN)  J1.SH(SHIELD)  C1.2()  C2.2()  U5.3(GND)  U5.8(GND)  U6.1(GND)  U3.2(GND)  C5.2()  C6.2()  C7.2()  R2.2()  U1.46(TEST)  U1.65(VSS(EP))  Y1.2(G)  Y1.4(G)  C8.2()  C9.2()  R3.2()  R4.2()  C10.2()  C11.2()  R6.2()  U4.5(GND)  U4.6(ORG)  C12.2()  C13.2()  C14.2()  C15.2()  C16.2()  C17.2()  C18.2()  C19.2()  C20.2()  C21.2()  C22.2()  C23.2()  C24.2()  C25.2()  C26.2()  C27.2()  C28.2()  C29.2()  C30.2()  C31.2()  R23.2()  U2.15(CONFIG)  U2.10(VDDO_SEL)  U2.57(VSS(EP))  Y2.2(G)  Y2.4(G)  C32.2()  C33.2()  R24.2()  C35.2()  C36.2()  C37.2()  C38.2()  C39.2()  C40.2()  C41.2()  C42.2()  C43.2()  C44.2()  C45.2()  C46.2()  C47.2()  C48.2()  C49.2()  C50.2()  J2.10(CHS_GND)  J2.SH(SHIELD)  C51.2()
LAN_1V2        U1.22(VDD12_SW_FB)  U1.28(VDD12CORE)  U1.54(VDD12CORE)  U1.37(VDD12A)  U1.42(VDD12A)  U1.62(VDD12A)  L2.2(2)  C13.1()  C14.1()  C15.1()  C16.1()  C17.1()  C18.1()  C19.1()
LAN_2V5        U1.63(VDD25_REG_OUT)  C20.1()
LAN_CLK125     U1.19(CLK125)  R6.1()  R7.1()
LAN_REF_FILT   U1.2(REF_FILT)  C10.1()
LAN_REF_REXT   U1.1(REF_REXT)  R4.1()
LAN_RESET_N    U1.47(RESET_N/PME_CLEAR)  R5.2()  C11.1()
LAN_SW         U1.20(VDD12_SW_OUT)  L2.1(1)
LAN_TXC        U1.10(TXC)  R9.1()
LAN_TXD0       U1.8(TXD0)  R11.1()
LAN_TXD1       U1.6(TXD1)  R12.1()
LAN_TXD2       U1.5(TXD2)  R13.1()
LAN_TXD3       U1.4(TXD3)  R14.1()
LAN_TX_CTL     U1.9(TX_CTL)  R10.1()
LAN_USB3_TXN   C4.1()  U1.41(USB3_TXDM)
LAN_USB3_TXP   C3.1()  U1.40(USB3_TXDP)
LAN_USBRBIAS   U1.49(USBRBIAS)  R3.1()
LAN_XI         U1.52(XI)  Y1.1(1)  C8.1()
LAN_XO         U1.53(XO)  Y1.3(3)  C9.1()
LED_A0         J2.11(LED_G+)  R25.2()
LED_A1         J2.14(LED_Y+)  R26.2()
MDC            U1.56(MDC)  U2.7(MDC)
MDI0_N         U2.27(MDIN[0])  J2.3(MDI0-)
MDI0_P         U2.28(MDIP[0])  J2.2(MDI0+)
MDI1_N         U2.23(MDIN[1])  J2.7(MDI1-)
MDI1_P         U2.24(MDIP[1])  J2.4(MDI1+)
MDI2_N         U2.21(MDIN[2])  J2.6(MDI2-)
MDI2_P         U2.22(MDIP[2])  J2.5(MDI2+)
MDI3_N         U2.17(MDIN[3])  J2.9(MDI3-)
MDI3_P         U2.18(MDIP[3])  J2.8(MDI3+)
MDIO           U1.55(MDIO)  R21.2()  U2.8(MDIO)
MDI_CT         J2.1(CT)  C51.1()
PHY_1V0        U2.40(DVDD_OUT)  U2.6(DVDD)  U2.42(DVDD)  C48.1()  C49.1()  C50.1()
PHY_1V8        U2.39(AVDD18_OUT)  U2.3(AVDD18)  U2.19(AVDD18)  U2.26(AVDD18)  U2.38(AVDD18)  U2.35(AVDDC18)  C42.1()  C43.1()  C44.1()  C45.1()  C46.1()  C47.1()
PHY_CLK125     R7.2()  U2.9(CLK125)
PHY_INT_N      U1.31(PHY_INT_N)  R22.2()  U2.12(LED[2]/INTn)
PHY_LED0       U2.14(LED[0])  J2.12(LED_G-)
PHY_LED1       U2.13(LED[1])  J2.13(LED_Y-)
PHY_REGCAP1    U2.37(REGCAP1)  C34.1()
PHY_REGCAP2    U2.41(REGCAP2)  C34.2()
PHY_RESET_N    U1.32(PHY_RESET_N)  R23.1()  U2.16(RESETn)
PHY_RSET       U2.30(RSET)  R24.1()
PHY_RXC        R15.1()  U2.46(RX_CLK)
PHY_RXD0       R17.1()  U2.44(RXD[0])
PHY_RXD1       R18.1()  U2.45(RXD[1])
PHY_RXD2       R19.1()  U2.47(RXD[2])
PHY_RXD3       R20.1()  U2.48(RXD[3])
PHY_RX_CTL     R16.1()  U2.43(RX_CTRL)
PHY_XI         U2.34(XTAL_IN)  Y2.1(1)  C32.1()
PHY_XO         U2.33(XTAL_OUT)  Y2.3(3)  C33.1()
RGMII_RXC      U1.12(RXC)  R15.2()
RGMII_RXD0     U1.14(RXD0)  R17.2()
RGMII_RXD1     U1.15(RXD1)  R18.2()
RGMII_RXD2     U1.16(RXD2)  R19.2()
RGMII_RXD3     U1.17(RXD3)  R20.2()
RGMII_RX_CTL   U1.13(RX_CTL)  R16.2()
RGMII_TXC      R9.2()  U2.53(TX_CLK)
RGMII_TXD0     R11.2()  U2.50(TXD[0])
RGMII_TXD1     R12.2()  U2.51(TXD[1])
RGMII_TXD2     R13.2()  U2.54(TXD[2])
RGMII_TXD3     R14.2()  U2.55(TXD[3])
RGMII_TX_CTL   R10.2()  U2.56(TX_CTRL)
USB_DM         J1.2(D-)  U6.3(I/O2)  U1.39(USB2_DM)
USB_DP         J1.3(D+)  U6.2(I/O1)  U1.38(USB2_DP)
USB_SSRX_N     J1.5(SSRX-)  U5.5(D2-)  C4.2()
USB_SSRX_P     J1.6(SSRX+)  U5.4(D2+)  C3.2()
USB_SSTX_N     J1.8(SSTX-)  U5.2(D1-)  U1.44(USB3_RXDM)
USB_SSTX_P     J1.9(SSTX+)  U5.1(D1+)  U1.43(USB3_RXDP)
VBUS           J1.1(VBUS)  FB1.1()

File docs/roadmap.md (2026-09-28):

# ND-2 roadmap

The plan is to prove the risky part first (the TDR test port), then build outward.

## Stage 1: TDR proof dongle, Rev A *(in progress)*

LAN7801 + 88E1512 + magjack on a small 4-layer USB 3 dongle.

- [x] Schematic (ERC clean), LCSC parts, footprints
- [x] PCB layout and routing (DRC clean, schematic parity clean)
- [x] Fab package (Gerbers, BOM, CPL) and JLCPCB order
- [ ] Boards arrive, hand-solder J1 (USB plug) and J2 (RJ45)
- [ ] Bring-up: power rails, USB enumeration, EEPROM, link ([bring-up.md](bring-up.md))
- [ ] Prove `ethtool --cable-test` and `--cable-test-tdr` on known-good and known-bad cables
- [ ] Write up results: accuracy vs. real cable lengths, open/short detection per pair

**Exit criteria:** a stable 1 Gb/s link with no CRC errors, and cable-test results that match reality on a set of test cables.

## Stage 2: TDR dongle, Rev B (a product in its own right)

If Rev A works, the dongle is already useful on its own: plug it into any Pi 5 or Linux laptop and you have a TDR cable tester. Rev B makes it something people can build or buy:

- USB-C receptacle + cable instead of the hard USB-A plug
- All-SMD connectors so the whole board fits JLCPCB Economic assembly
- Swap passives to JLC "basic" parts to cut assembly fees
- Length-matched, impedance-controlled USB 3 and MDI pairs
- Low-capacitance TVS on the MDI pairs
- 3D-printed case
- Packaged `nd2-cabletest` software (Debian package / pip)
- Possible small batches on Tindie

## Stage 3: ND-2 carrier board

The full handheld from [spec.md](spec.md):

- CM5 carrier with the proven test-port circuit copied in
- CM5 native gigabit port as the uplink
- USB 3 hub + 2x USB-A, M.2 2230, microSD, HDMI
- DSI touchscreen
- USB-C PD input, 2S Li-ion with BQ25798 charger and fuel gauge
- Case

## Stage 4: software

- Touch GUI (LVGL on Linux DRM, sharing its look with ND-1)
- Modes: cable test, link/speed test, capture, inline tap (bridge), iperf3, scan
- Report export (HTML/PDF) for cable-test results

## Ideas parked for later

- Remote wiremap unit, for split-pair detection
- Relay-based fail-open bypass for the inline tap
- PoE detection / measurement on the test port

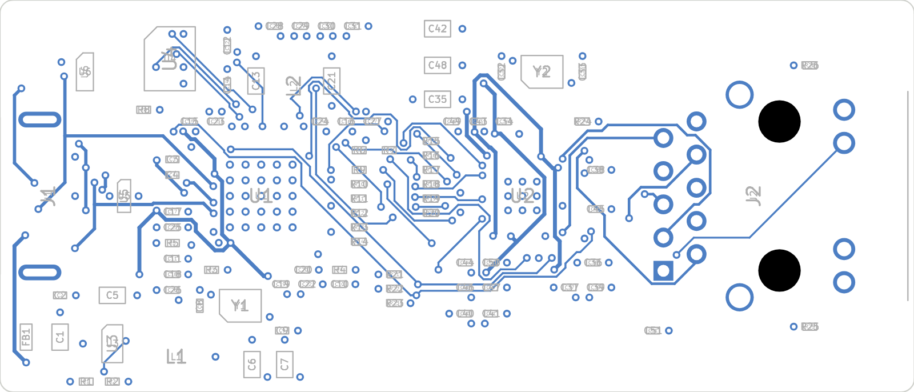
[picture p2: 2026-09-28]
hardware/tdr-dongle/fab/render_bottom.png

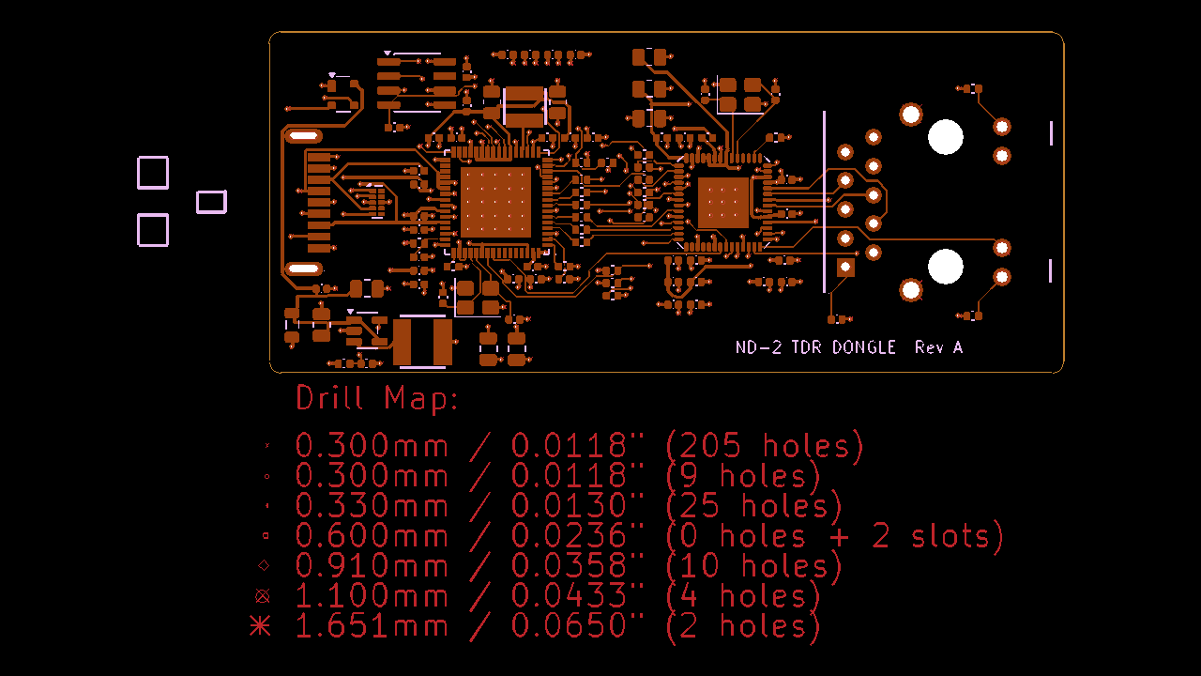
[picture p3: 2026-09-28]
docs/images/tdr-dongle-jlc-preview.png

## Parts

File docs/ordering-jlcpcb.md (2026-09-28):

# Ordering the TDR dongle from JLCPCB

Files are in [`hardware/tdr-dongle/fab/`](../hardware/tdr-dongle/fab/).

## PCB settings

| Option | Setting | Why |
|---|---|---|
| Gerber upload | `tdr-dongle_gerbers_JLC.zip` | |
| Layers | 4 | GND and +3V3 planes on the inner layers |
| Dimensions | 70 x 30 mm | auto-detected |
| PCB thickness | 1.6 mm | |
| Stackup | JLC04161H-7628, or "Specify Stackup: No" (it's the default) | the board was designed for it |
| Surface finish | HASL (leaded) or ENIG | ENIG is flatter for the 0.5 mm QFNs, but HASL works fine for machine assembly |
| Outer / inner copper | 1 oz / 0.5 oz | |
| Via covering | Plugged | |
| Min via hole / diameter | 0.3 mm / (0.4–0.45 mm) | vias are 0.3 / 0.6 mm |
| Min track | standard | 0.1 mm at the QFN pins, fine for JLC 4-layer |
| Mark on PCB | Remove Mark | |
| Confirm production file | Yes (recommended) | review JLC's processed files before they build |

## Assembly settings

| Option | Setting |
|---|---|
| PCBA type | **Economic**, top side |
| Assembly quantity | **2** (of 5 bare boards), plenty for a proof board |
| BOM | `tdr-dongle_BOM_JLC.csv` |
| CPL | `tdr-dongle_CPL_JLC.csv` |
| Do not place | **J1 (USB plug) and J2 (RJ45)**: through-hole/edge parts push the order to Standard assembly. Hand-solder them. |

In the placement preview, check pin 1 on U1, U2, U3 and U4, and the orientation of Y1, Y2, U5 and U6.

## Hand-soldered parts to buy separately

| Ref | Part | LCSC | Notes |
|---|---|---|---|
| J1 | HC-USB3.0-C26 USB 3 Type-A plug (SMD) | C7501854 | Generic "USB 3.0 A male SMT 9-pin" plugs can work if the 9 pins are **one row at 1.0 mm pitch** and the 2 shield legs are about **11.7 mm** apart |
| J2 | HanRun HR911130C 1G magjack | C50933 | Exact part only; other magjacks don't share its pinout |

## Cost notes (Sept 2026, 5 PCBs / 2 assembled, US shipping)

- The first quote (Standard, 5 assembled, ENIG, connectors placed) was about **$294**.
- Economic, 2 assembled, connectors not placed, HASL: about **$160 + shipping/customs**.
- The biggest costs are the parts themselves (LAN7801 and 88E1512) and the ~$3 loading fee per *extended* part. Rev B will switch passives to JLC basic parts.

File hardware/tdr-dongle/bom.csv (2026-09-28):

Ref | Value | Footprint | DNP | MPN | LCSC
C1 | 10uF | Capacitor_SMD:C_0805_2012Metric |  | CL21A106KAYNNNE | C15850
C2 | 100nF | Capacitor_SMD:C_0402_1005Metric |  | CL05B104KO5NNNC | C1525
C3 | 100nF | Capacitor_SMD:C_0402_1005Metric |  | CL05B104KO5NNNC | C1525
C4 | 100nF | Capacitor_SMD:C_0402_1005Metric |  | CL05B104KO5NNNC | C1525
C5 | 10uF | Capacitor_SMD:C_0805_2012Metric |  | CL21A106KAYNNNE | C15850
C6 | 22uF | Capacitor_SMD:C_0805_2012Metric |  | CL21A226MAQNNNE | C45783
C7 | 22uF | Capacitor_SMD:C_0805_2012Metric |  | CL21A226MAQNNNE | C45783
C8 | 15pF | Capacitor_SMD:C_0402_1005Metric |  | 0402CG150J500NT | C1548
C9 | 15pF | Capacitor_SMD:C_0402_1005Metric |  | 0402CG150J500NT | C1548
C10 | 1uF | Capacitor_SMD:C_0402_1005Metric |  | CL05A105KA5NQNC | C52923
C11 | 100nF | Capacitor_SMD:C_0402_1005Metric |  | CL05B104KO5NNNC | C1525
C12 | 100nF | Capacitor_SMD:C_0402_1005Metric |  | CL05B104KO5NNNC | C1525
C13 | 22uF | Capacitor_SMD:C_0805_2012Metric |  | CL21A226MAQNNNE | C45783
C14 | 1uF | Capacitor_SMD:C_0402_1005Metric |  | CL05A105KA5NQNC | C52923
C15 | 100nF | Capacitor_SMD:C_0402_1005Metric |  | CL05B104KO5NNNC | C1525
C16 | 100nF | Capacitor_SMD:C_0402_1005Metric |  | CL05B104KO5NNNC | C1525
C17 | 100nF | Capacitor_SMD:C_0402_1005Metric |  | CL05B104KO5NNNC | C1525
C18 | 100nF | Capacitor_SMD:C_0402_1005Metric |  | CL05B104KO5NNNC | C1525
C19 | 100nF | Capacitor_SMD:C_0402_1005Metric |  | CL05B104KO5NNNC | C1525
C20 | 1uF | Capacitor_SMD:C_0402_1005Metric |  | CL05A105KA5NQNC | C52923
C21 | 10uF | Capacitor_SMD:C_0805_2012Metric |  | CL21A106KAYNNNE | C15850
C22 | 1uF | Capacitor_SMD:C_0402_1005Metric |  | CL05A105KA5NQNC | C52923
C23 | 100nF | Capacitor_SMD:C_0402_1005Metric |  | CL05B104KO5NNNC | C1525
C24 | 100nF | Capacitor_SMD:C_0402_1005Metric |  | CL05B104KO5NNNC | C1525
C25 | 100nF | Capacitor_SMD:C_0402_1005Metric |  | CL05B104KO5NNNC | C1525
C26 | 100nF | Capacitor_SMD:C_0402_1005Metric |  | CL05B104KO5NNNC | C1525
C27 | 100nF | Capacitor_SMD:C_0402_1005Metric |  | CL05B104KO5NNNC | C1525
C28 | 100nF | Capacitor_SMD:C_0402_1005Metric |  | CL05B104KO5NNNC | C1525
C29 | 100nF | Capacitor_SMD:C_0402_1005Metric |  | CL05B104KO5NNNC | C1525
C30 | 100nF | Capacitor_SMD:C_0402_1005Metric |  | CL05B104KO5NNNC | C1525
C31 | 100nF | Capacitor_SMD:C_0402_1005Metric |  | CL05B104KO5NNNC | C1525
C32 | 15pF | Capacitor_SMD:C_0402_1005Metric |  | 0402CG150J500NT | C1548
C33 | 15pF | Capacitor_SMD:C_0402_1005Metric |  | 0402CG150J500NT | C1548
C34 | 220nF | Capacitor_SMD:C_0402_1005Metric |  | CL05B224KO5NNNC | C16772
C35 | 10uF | Capacitor_SMD:C_0805_2012Metric |  | CL21A106KAYNNNE | C15850
C36 | 100nF | Capacitor_SMD:C_0402_1005Metric |  | CL05B104KO5NNNC | C1525
C37 | 100nF | Capacitor_SMD:C_0402_1005Metric |  | CL05B104KO5NNNC | C1525
C38 | 100nF | Capacitor_SMD:C_0402_1005Metric |  | CL05B104KO5NNNC | C1525
C39 | 100nF | Capacitor_SMD:C_0402_1005Metric |  | CL05B104KO5NNNC | C1525
C40 | 100nF | Capacitor_SMD:C_0402_1005Metric |  | CL05B104KO5NNNC | C1525
C41 | 100nF | Capacitor_SMD:C_0402_1005Metric |  | CL05B104KO5NNNC | C1525
C42 | 10uF | Capacitor_SMD:C_0805_2012Metric |  | CL21A106KAYNNNE | C15850
C43 | 100nF | Capacitor_SMD:C_0402_1005Metric |  | CL05B104KO5NNNC | C1525
C44 | 100nF | Capacitor_SMD:C_0402_1005Metric |  | CL05B104KO5NNNC | C1525
C45 | 100nF | Capacitor_SMD:C_0402_1005Metric |  | CL05B104KO5NNNC | C1525
C46 | 100nF | Capacitor_SMD:C_0402_1005Metric |  | CL05B104KO5NNNC | C1525
C47 | 100nF | Capacitor_SMD:C_0402_1005Metric |  | CL05B104KO5NNNC | C1525
C48 | 10uF | Capacitor_SMD:C_0805_2012Metric |  | CL21A106KAYNNNE | C15850
C49 | 100nF | Capacitor_SMD:C_0402_1005Metric |  | CL05B104KO5NNNC | C1525
C50 | 100nF | Capacitor_SMD:C_0402_1005Metric |  | CL05B104KO5NNNC | C1525
C51 | 100nF | Capacitor_SMD:C_0402_1005Metric |  | CL05B104KO5NNNC | C1525
FB1 | 600R | Inductor_SMD:L_0805_2012Metric |  | MPZ2012S601AT000 | C21519
J1 | HC-USB3.0-C26 | ND2:USB3_A_Plug_HongCheng_HC-USB3.0-C26 |  | HC-USB3.0-C26 | C7501854
J2 | HR911130C | ND2:RJ45_HanRun_HR911130C_Horizontal |  | HR911130C | C50933
L1 | 2.2uH | ND2:L_4.0x4.0mm_SMNR4020 |  | SMNR4020-2.2UH | C135262
L2 | 3.3uH | ND2:L_3.0x3.0mm_SMNR3015 |  | SMNR3015-3R3MT | C135239
R1 | 453k | Resistor_SMD:R_0402_1005Metric |  | 0402WGF4533TCE | C27009
R2 | 100k | Resistor_SMD:R_0402_1005Metric |  | 0402WGF1003TCE | C25741
R3 | 12k | Resistor_SMD:R_0402_1005Metric |  | 0402WGF1202TCE | C25752
R4 | 2k | Resistor_SMD:R_0402_1005Metric |  | 0402WGF2001TCE | C4109
R5 | 10k | Resistor_SMD:R_0402_1005Metric |  | 0402WGF1002TCE | C25744
R6 | 10k | Resistor_SMD:R_0402_1005Metric |  | 0402WGF1002TCE | C25744
R7 | 0R | Resistor_SMD:R_0402_1005Metric | DNP | 0402WGF0000TCE | C17168
R8 | 10k | Resistor_SMD:R_0402_1005Metric |  | 0402WGF1002TCE | C25744
R9 | 22R | Resistor_SMD:R_0402_1005Metric |  | 0402WGF220JTCE | C25092
R10 | 22R | Resistor_SMD:R_0402_1005Metric |  | 0402WGF220JTCE | C25092
R11 | 22R | Resistor_SMD:R_0402_1005Metric |  | 0402WGF220JTCE | C25092
R12 | 22R | Resistor_SMD:R_0402_1005Metric |  | 0402WGF220JTCE | C25092
R13 | 22R | Resistor_SMD:R_0402_1005Metric |  | 0402WGF220JTCE | C25092
R14 | 22R | Resistor_SMD:R_0402_1005Metric |  | 0402WGF220JTCE | C25092
R15 | 22R | Resistor_SMD:R_0402_1005Metric |  | 0402WGF220JTCE | C25092
R16 | 22R | Resistor_SMD:R_0402_1005Metric |  | 0402WGF220JTCE | C25092
R17 | 22R | Resistor_SMD:R_0402_1005Metric |  | 0402WGF220JTCE | C25092
R18 | 22R | Resistor_SMD:R_0402_1005Metric |  | 0402WGF220JTCE | C25092
R19 | 22R | Resistor_SMD:R_0402_1005Metric |  | 0402WGF220JTCE | C25092
R20 | 22R | Resistor_SMD:R_0402_1005Metric |  | 0402WGF220JTCE | C25092
R21 | 1.5k | Resistor_SMD:R_0402_1005Metric |  | 0402WGF1501TCE | C25867
R22 | 10k | Resistor_SMD:R_0402_1005Metric |  | 0402WGF1002TCE | C25744
R23 | 10k | Resistor_SMD:R_0402_1005Metric |  | 0402WGF1002TCE | C25744
R24 | 4.99k | Resistor_SMD:R_0402_1005Metric |  | 0402WGF4991TCE | C25903
R25 | 330R | Resistor_SMD:R_0402_1005Metric |  | 0402WGF3300TCE | C25104
R26 | 330R | Resistor_SMD:R_0402_1005Metric |  | 0402WGF3300TCE | C25104
U1 | LAN7801-I/9JX | ND2:LAN7801_QFN-64-1EP_9x9mm_P0.5mm_EP6.1mm |  | LAN7801-I/9JX | C633491
U2 | 88E1512-A0-NNP2C000 | ND2:88E1512_QFN-56-1EP_8x8mm_P0.5mm_EP4.4mm |  | 88E1512-A0-NNP2C000 | C845579
U3 | TLV62569DBV | Package_TO_SOT_SMD:SOT-23-5 |  | TLV62569DBVR | C141836
U4 | 93AA66/SN | Package_SO:SOIC-8_3.9x4.9mm_P1.27mm |  | 93AA66/SN | C615340
U5 | TPD4EUSB30 | Package_SON:USON-10_2.5x1.0mm_P0.5mm |  | TPD4EUSB30DQAR | C90627
U6 | PRTR5V0U2X | Package_TO_SOT_SMD:SOT-143 |  | PRTR5V0U2X,215 | C12333
Y1 | 25MHz | Crystal:Crystal_SMD_3225-4Pin_3.2x2.5mm |  | X322525MOB4SI | C9006
Y2 | 25MHz | Crystal:Crystal_SMD_3225-4Pin_3.2x2.5mm |  | X322525MOB4SI | C9006

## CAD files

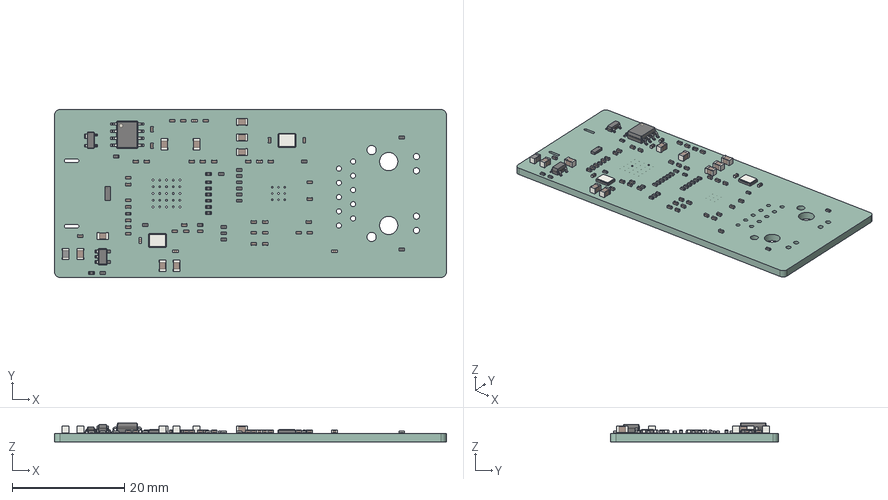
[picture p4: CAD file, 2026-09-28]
hardware/tdr-dongle/fab/tdr-dongle.step
70.0 x 30.0 x 3.34 mm
R_0402_1005Metric x 26
C_0402_1005Metric x 42
C_0805_2012Metric x 9
USON_10_25x10mm_Pitch05mm
SOIC-8_3.9x4.9mm_P1.27mm
Crystal_SMD_3225-4Pin_3.2x2.5mm x 2
L_0805_2012Metric
SOT-143
SOT-23-5
tdr-dongle_PCB

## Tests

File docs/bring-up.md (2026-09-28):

# TDR dongle bring-up (Rev A)

A careful first power-on for the Rev A boards. Work top to bottom and stop at the first thing that looks wrong.

You'll need: a multimeter, a current-limited USB supply or USB power meter, a Pi 5 (or any Linux machine with USB 3), and a few known Ethernet cables (good, one with an open pair, one with a short, known lengths).

## 0. Before soldering the connectors

JLCPCB assembles every SMD part. J1 (USB 3 plug) and J2 (RJ45 magjack) are hand-soldered.

- Inspect U1 (LAN7801) and U2 (88E1512) under magnification: no bridges on the 0.5 mm pins, parts square to their pads.
- Check pin 1 on U1, U2, U3 (buck) and U4 (EEPROM) against the silkscreen dot.
- Solder J2 (RJ45) first, then J1 (USB plug). J1's pins must sit flat on the 9 pads while its two shield legs drop into the slots.

## 1. Resistance checks (unpowered)

Measure to GND. None of these should be a dead short (under about 10 Ω):

| Net | Where to probe | Expect |
|---|---|---|
| VBUS / +5V | J1 VBUS pin, C1 | > 1 kΩ |
| +3V3 | C21, any 100 nF cap | > 100 Ω |
| LAN_1V2 | L2 output side | > 10 Ω (low-ish is normal for a core rail) |
| PHY rails | C44–C50 | not shorted |

## 2. First power

Use a current-limited supply (500 mA limit) or a USB power meter on a laptop/Pi port.

| Rail | Expected | Notes |
|---|---|---|
| +5V (VBUS) | 4.75–5.25 V | from the host |
| +3V3 | 3.25–3.35 V | TLV62569 buck (U3) |
| LAN_1V2 | ~1.2 V | LAN7801 internal switcher + L2 |
| LAN_2V5 | ~2.5 V | LAN7801 internal regulator |
| PHY_1V8 / PHY_1V0 | ~1.8 V / ~1.0 V | 88E1512 internal regulators |

Idle current should be a few hundred mA at most. If it's much higher, or anything gets hot, unplug and look for shorts.

## 3. USB enumeration

On the Pi 5:

```bash
lsusb                  # expect 0424:7801 (Microchip LAN7801)
dmesg | grep -i lan78  # lan78xx should bind and create an ethX interface
dmesg | grep -i phy    # expect a Marvell 88E1510-family PHY at MDIO address 0
```

- **No USB device:** check the 25 MHz crystal Y1, the VBUS path through FB1, and J1 soldering.
- **Shows as USB 2 only (480M in `lsusb -t`):** the USB 3 SuperSpeed pairs through J1 or U5 have a problem.

## 4. EEPROM (MAC address + RGMII config)

U4 (93AA66, 512 x 8) holds the LAN7801 config: MAC address, and settings that affect the RGMII clock and delays. A blank EEPROM leaves the driver on defaults with a random MAC, which is fine for first tests.

- Read it: `sudo ethtool -e ethX`
- Programming uses `ethtool -E ethX magic 0x78A5 offset <n> value <v>`. The exact byte layout is in the LAN7801 datasheet's EEPROM section. **TODO:** add a verified image and script to `software/` once tested on real boards.

## 5. Link test

```bash
sudo ip link set ethX up
ethtool ethX            # expect Speed: 1000Mb/s, Duplex: Full, Link detected: yes
iperf3 -c <server> -B <ethX-ip>
ip -s link show ethX    # RX errors / CRC should stay at 0
```

CRC errors or no traffic at 1000 Mb/s (while 100 Mb/s works) almost always means an **RGMII delay mismatch**. Try in this order:

1. PHY-side delays via the driver's phy-mode (`rgmii-id` / `rgmii-rxid` / `rgmii-txid`)
2. LAN7801-side delays via EEPROM
3. Check R9–R20 (22 Ω RGMII series resistors) are fitted and correct

## 6. Cable test (the point of all this)

Always unplug the far end of the cable first.

```bash
sudo ethtool --cable-test ethX       # per-pair status + fault distance
sudo ethtool --cable-test-tdr ethX   # raw TDR amplitude vs distance
```

Record results for:

| Cable | Expected | Result |
|---|---|---|
| 2 m known-good patch, far end open | all pairs "open" at ~2 m | |
| 10 m / 30 m known lengths, far end open | distance within about 1 m | |
| Cable with one pair cut | that pair "open" at cut distance | |
| Cable with a shorted pair | that pair "short" | |
| Good cable into a live switch | expect "unknown" or odd results (link partner) | |

Post results as an issue using the *Bring-up report* template.

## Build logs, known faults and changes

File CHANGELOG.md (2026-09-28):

# Changelog

## 2026-09-28: repo created

- ND-2 hardware spec (draft) in `docs/spec.md`
- TDR proof dongle Rev A: schematic, PCB (4-layer, DRC clean), fab files, BOM/CPL
- Rev A ordered from JLCPCB (5 PCBs, 2 assembled, J1/J2 hand-soldered)
- `nd2-cabletest.py` cable test wrapper (untested on hardware)
- Bring-up plan, JLCPCB ordering notes, roadmap

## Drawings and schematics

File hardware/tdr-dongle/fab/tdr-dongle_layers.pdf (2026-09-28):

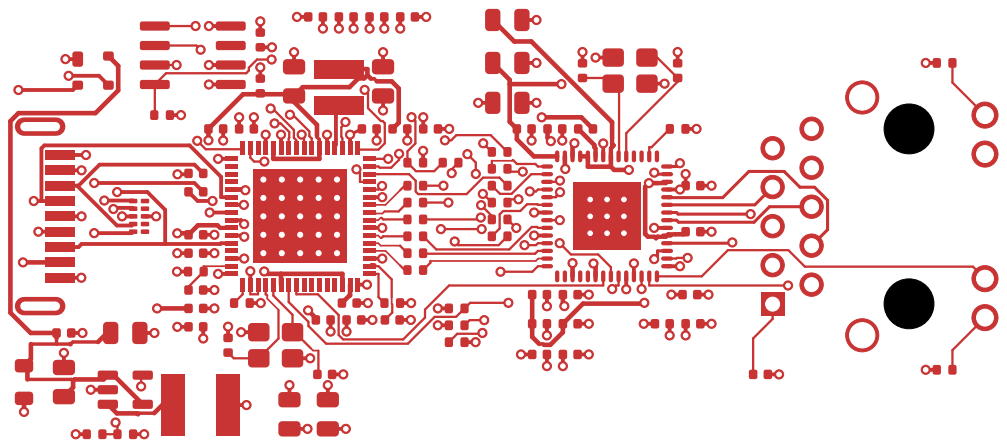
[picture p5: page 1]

Size: A4 | Rev:
KiCad E.D.A. 10.0.5 | Id: 1/7

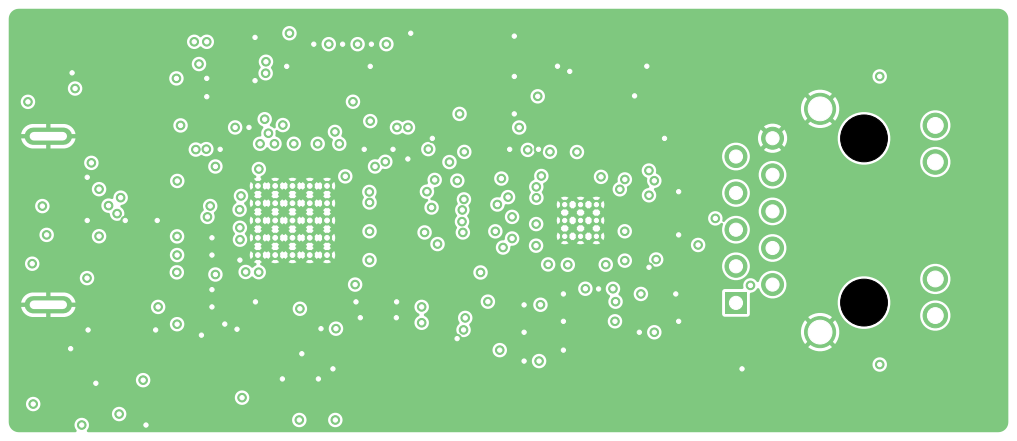
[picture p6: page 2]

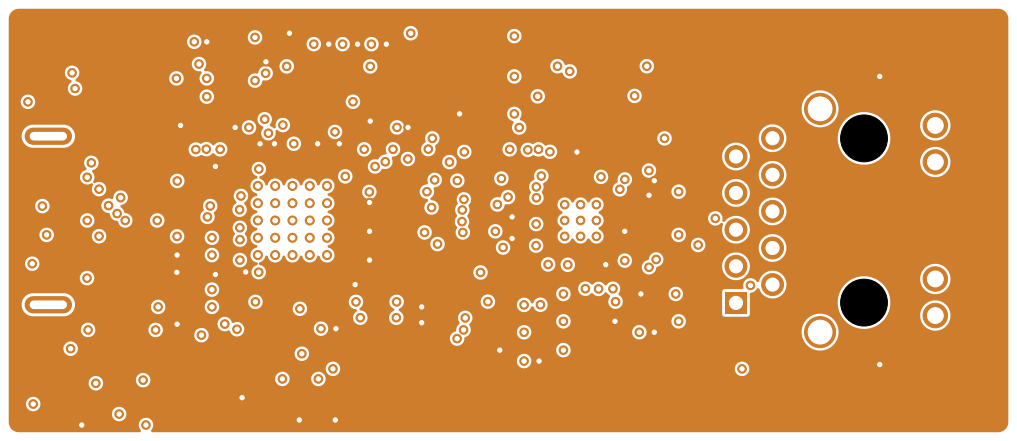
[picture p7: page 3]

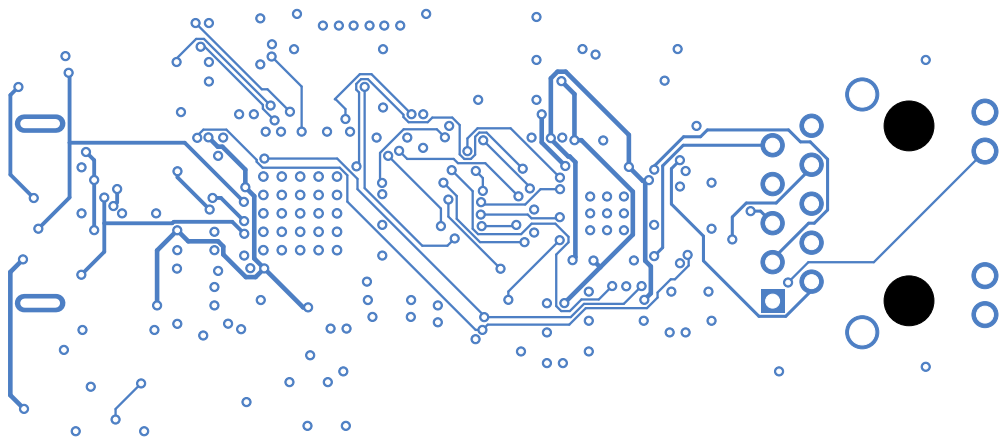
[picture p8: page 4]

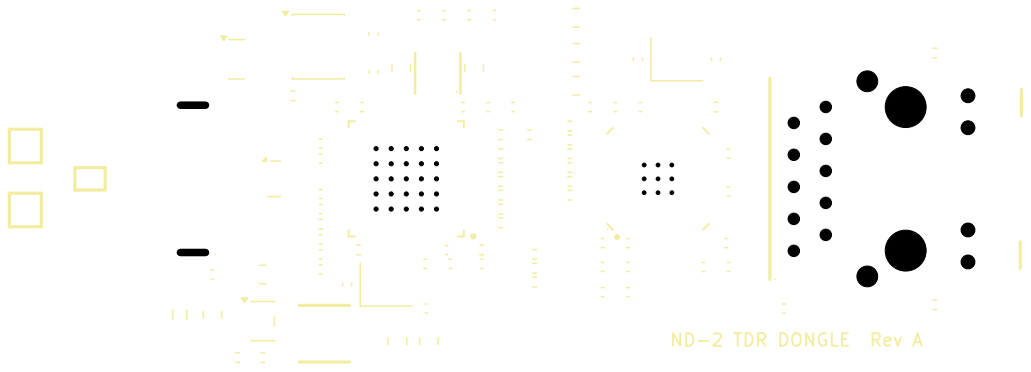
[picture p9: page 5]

ND-2 TDR DONGLE Rev A

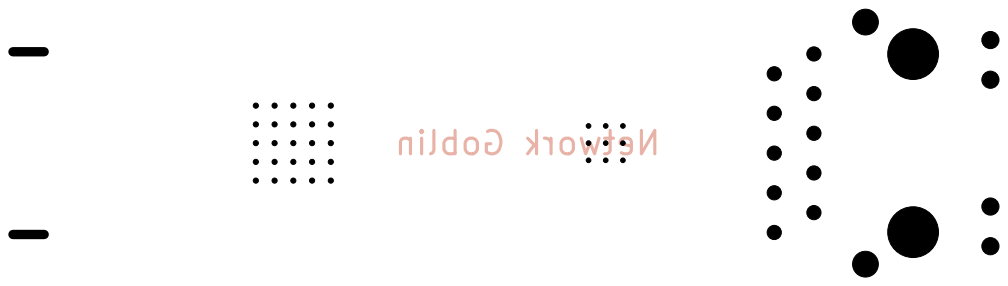
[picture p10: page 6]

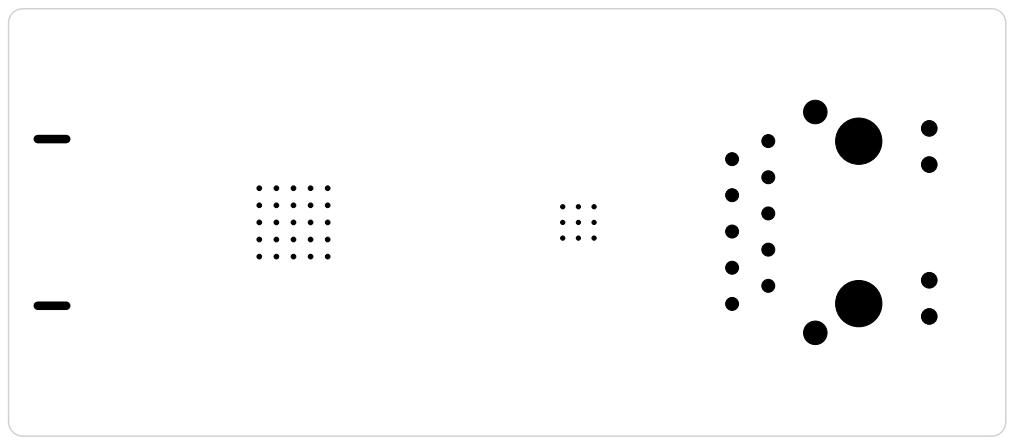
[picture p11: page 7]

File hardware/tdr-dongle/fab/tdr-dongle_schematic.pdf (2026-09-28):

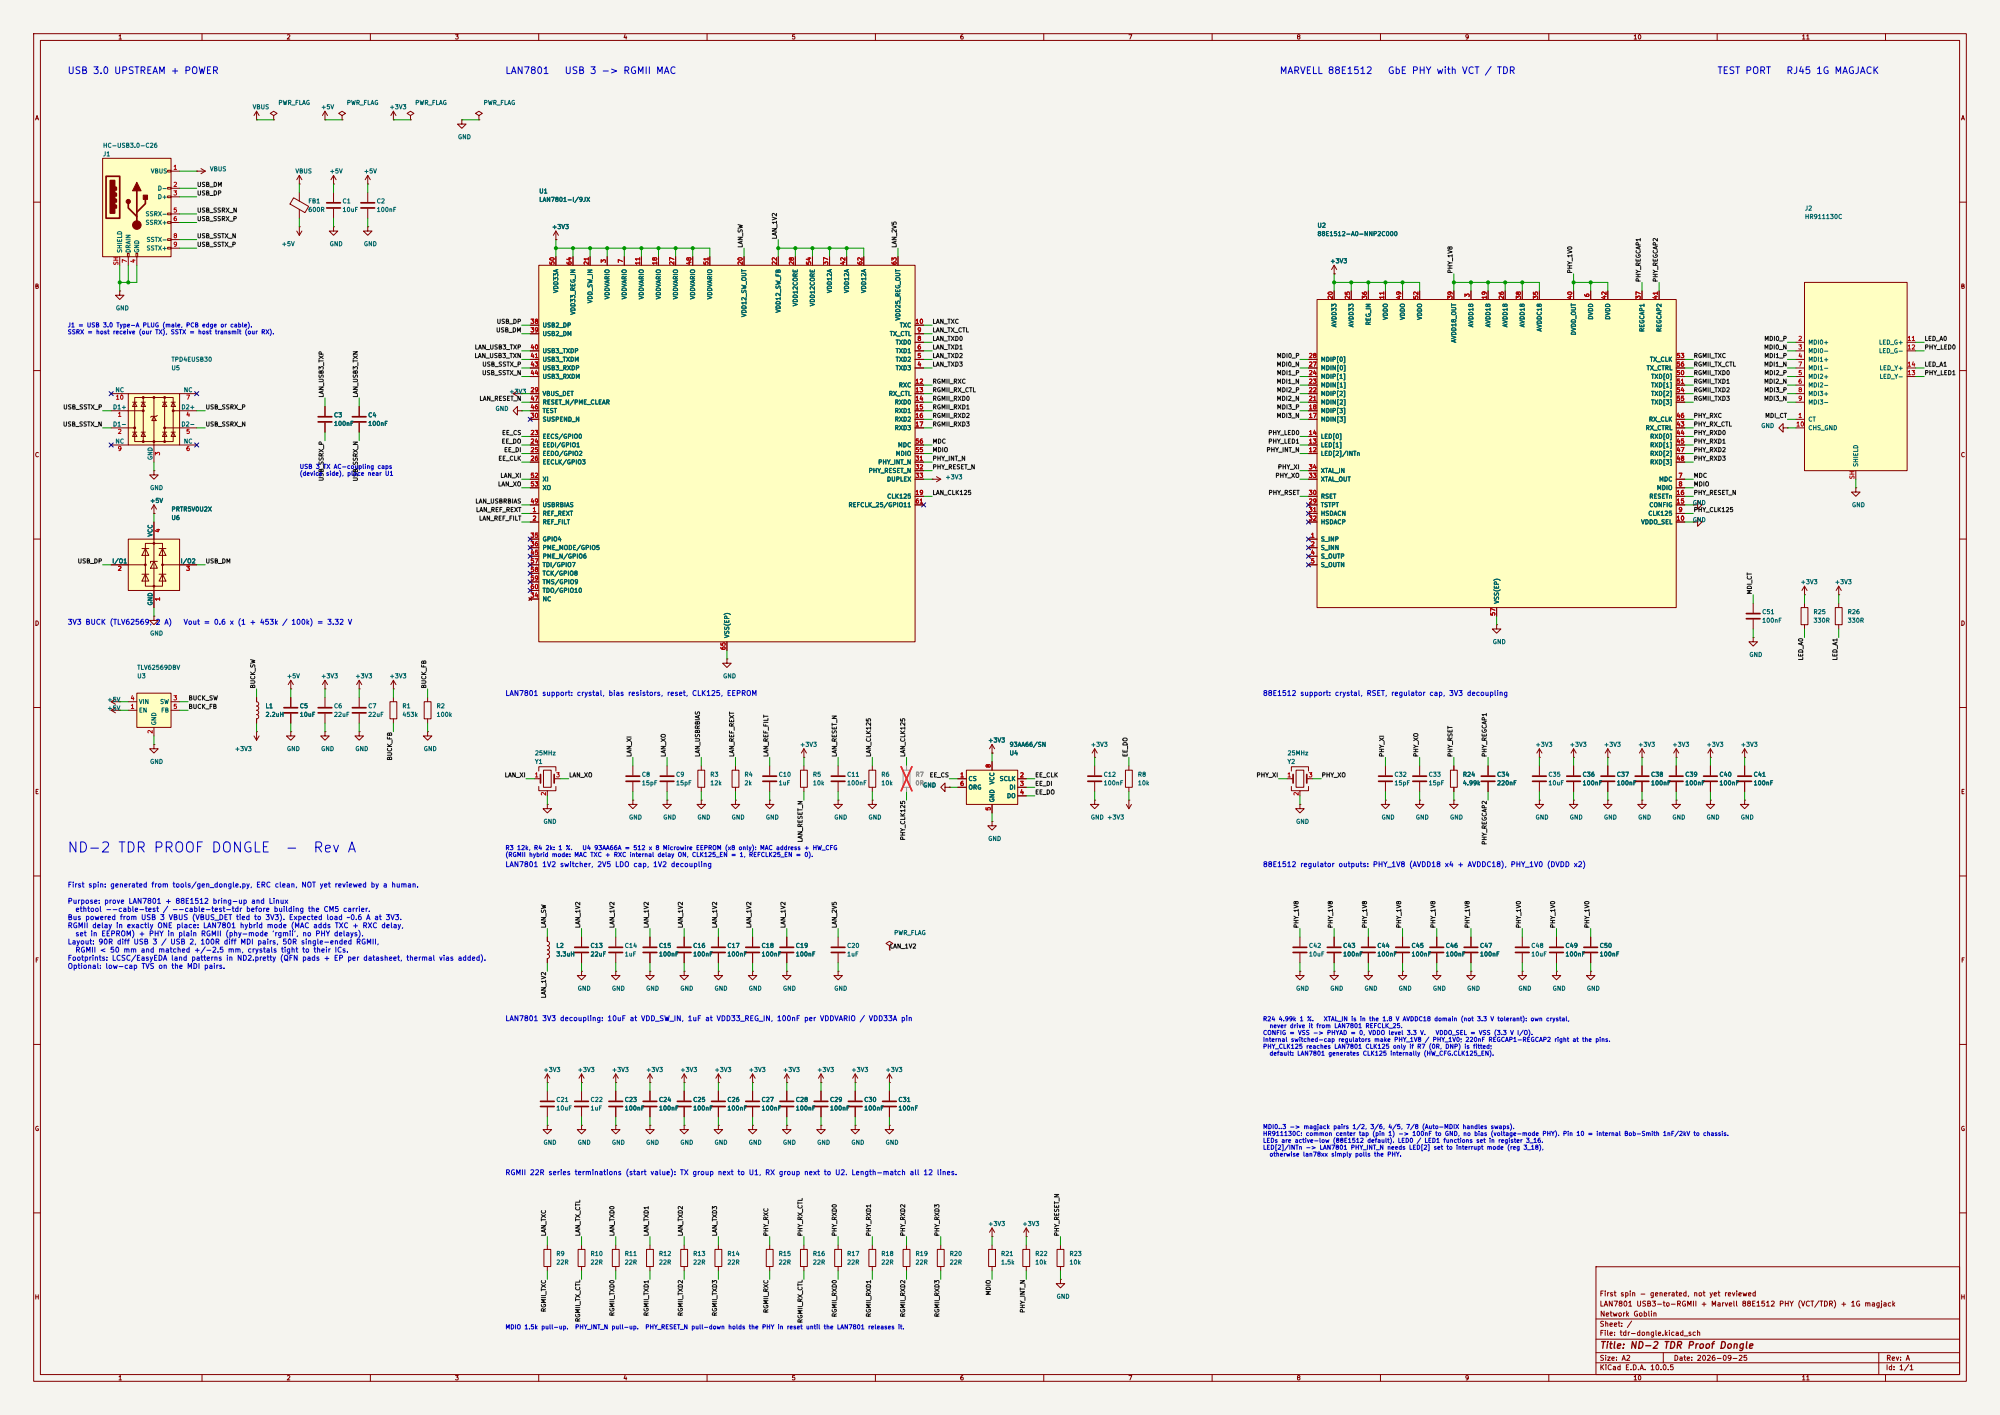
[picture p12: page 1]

J1 = USB 3.0 Type-A PLUG (male, PCB edge or cable). SSRX = host receive (our TX), SSTX = host transmit (our RX).

USB 3 TX AC-coupling caps

LAN7801 support: crystal, bias resistors, reset, CLK125, EEPROM

88E1512 support: crystal, RSET, regulator cap, 3V3 decoupling MDI0..3 -> magjack pairs 1/2, 3/6, 4/5, 7/8 (Auto-MDIX handles swaps). HR911130C: common center tap (pin 1) -> 100nF to GND, no bias (voltage-mode PHY). Pin 10 = internal Bob-Smith 1nF/2kV to chassis. LEDs are active-low (88E1512 default). LED0 / LED1 functions set in register 3_16. LED[2]/INTn -> LAN7801 PHY_INT_N needs LED[2] set to interrupt mode (reg 3_18), otherwise lan78xx simply polls the PHY.

ND-2 TDR PROOF DONGLE - Rev A

(RGMII hybrid mode: MAC TXC + RXC internal delay ON, CLK125_EN = 1, REFCLK25_EN = 0).
LAN7801 1V2 switcher, 2V5 LDO cap, 1V2 decoupling

First spin: generated from tools/gen_dongle.py, ERC clean, NOT yet reviewed by a human.

Purpose: prove LAN7801 + 88E1512 bring-up and Linux
ethtool --cable-test / --cable-test-tdr before building the CM5 carrier.
Bus powered from USB 3 VBUS (VBUS_DET tied to 3V3). Expected load ~0.6 A at 3V3.
RGMII delay in exactly ONE place: LAN7801 hybrid mode (MAC adds TXC + RXC delay,
set in EEPROM) + PHY in plain RGMII (phy-mode 'rgmii', no PHY delays).
Layout: 90R diff USB 3 / USB 2, 100R diff MDI pairs, 50R single-ended RGMII,
RGMII < 50 mm and matched +/-2.5 mm, crystals tight to their ICs.
Footprints: LCSC/EasyEDA land patterns in ND2.pretty (QFN pads + EP per datasheet, thermal vias added).
Optional: low-cap TVS on the MDI pairs.

LAN7801 3V3 decoupling: 10uF at VDD_SW_IN, 1uF at VDD33_REG_IN, 100nF per VDDVARIO / VDD33A pin

Internal switched-cap regulators make PHY_1V8 / PHY_1V0; 220nF REGCAP1-REGCAP2 right at the pins. PHY_CLK125 reaches LAN7801 CLK125 only if R7 (0R, DNP) is fitted; default: LAN7801 generates CLK125 internally (HW_CFG.CLK125_EN).

RGMII 22R series terminations (start value): TX group next to U1, RX group next to U2. Length-match all 12 lines.

First spin - generated, not yet reviewed
LAN7801 USB3-to-RGMII + Marvell 88E1512 PHY (VCT/TDR) + 1G magjack
Network Goblin
Sheet: /
File: tdr-dongle.kicad_sch
Title: ND-2 TDR Proof Dongle

MDIO 1.5k pull-up. PHY_INT_N pull-up. PHY_RESET_N pull-down holds the PHY in reset until the LAN7801 releases it.

Size: A2 | Rev: A
KiCad E.D.A. 10.0.5 | Id: 1/1

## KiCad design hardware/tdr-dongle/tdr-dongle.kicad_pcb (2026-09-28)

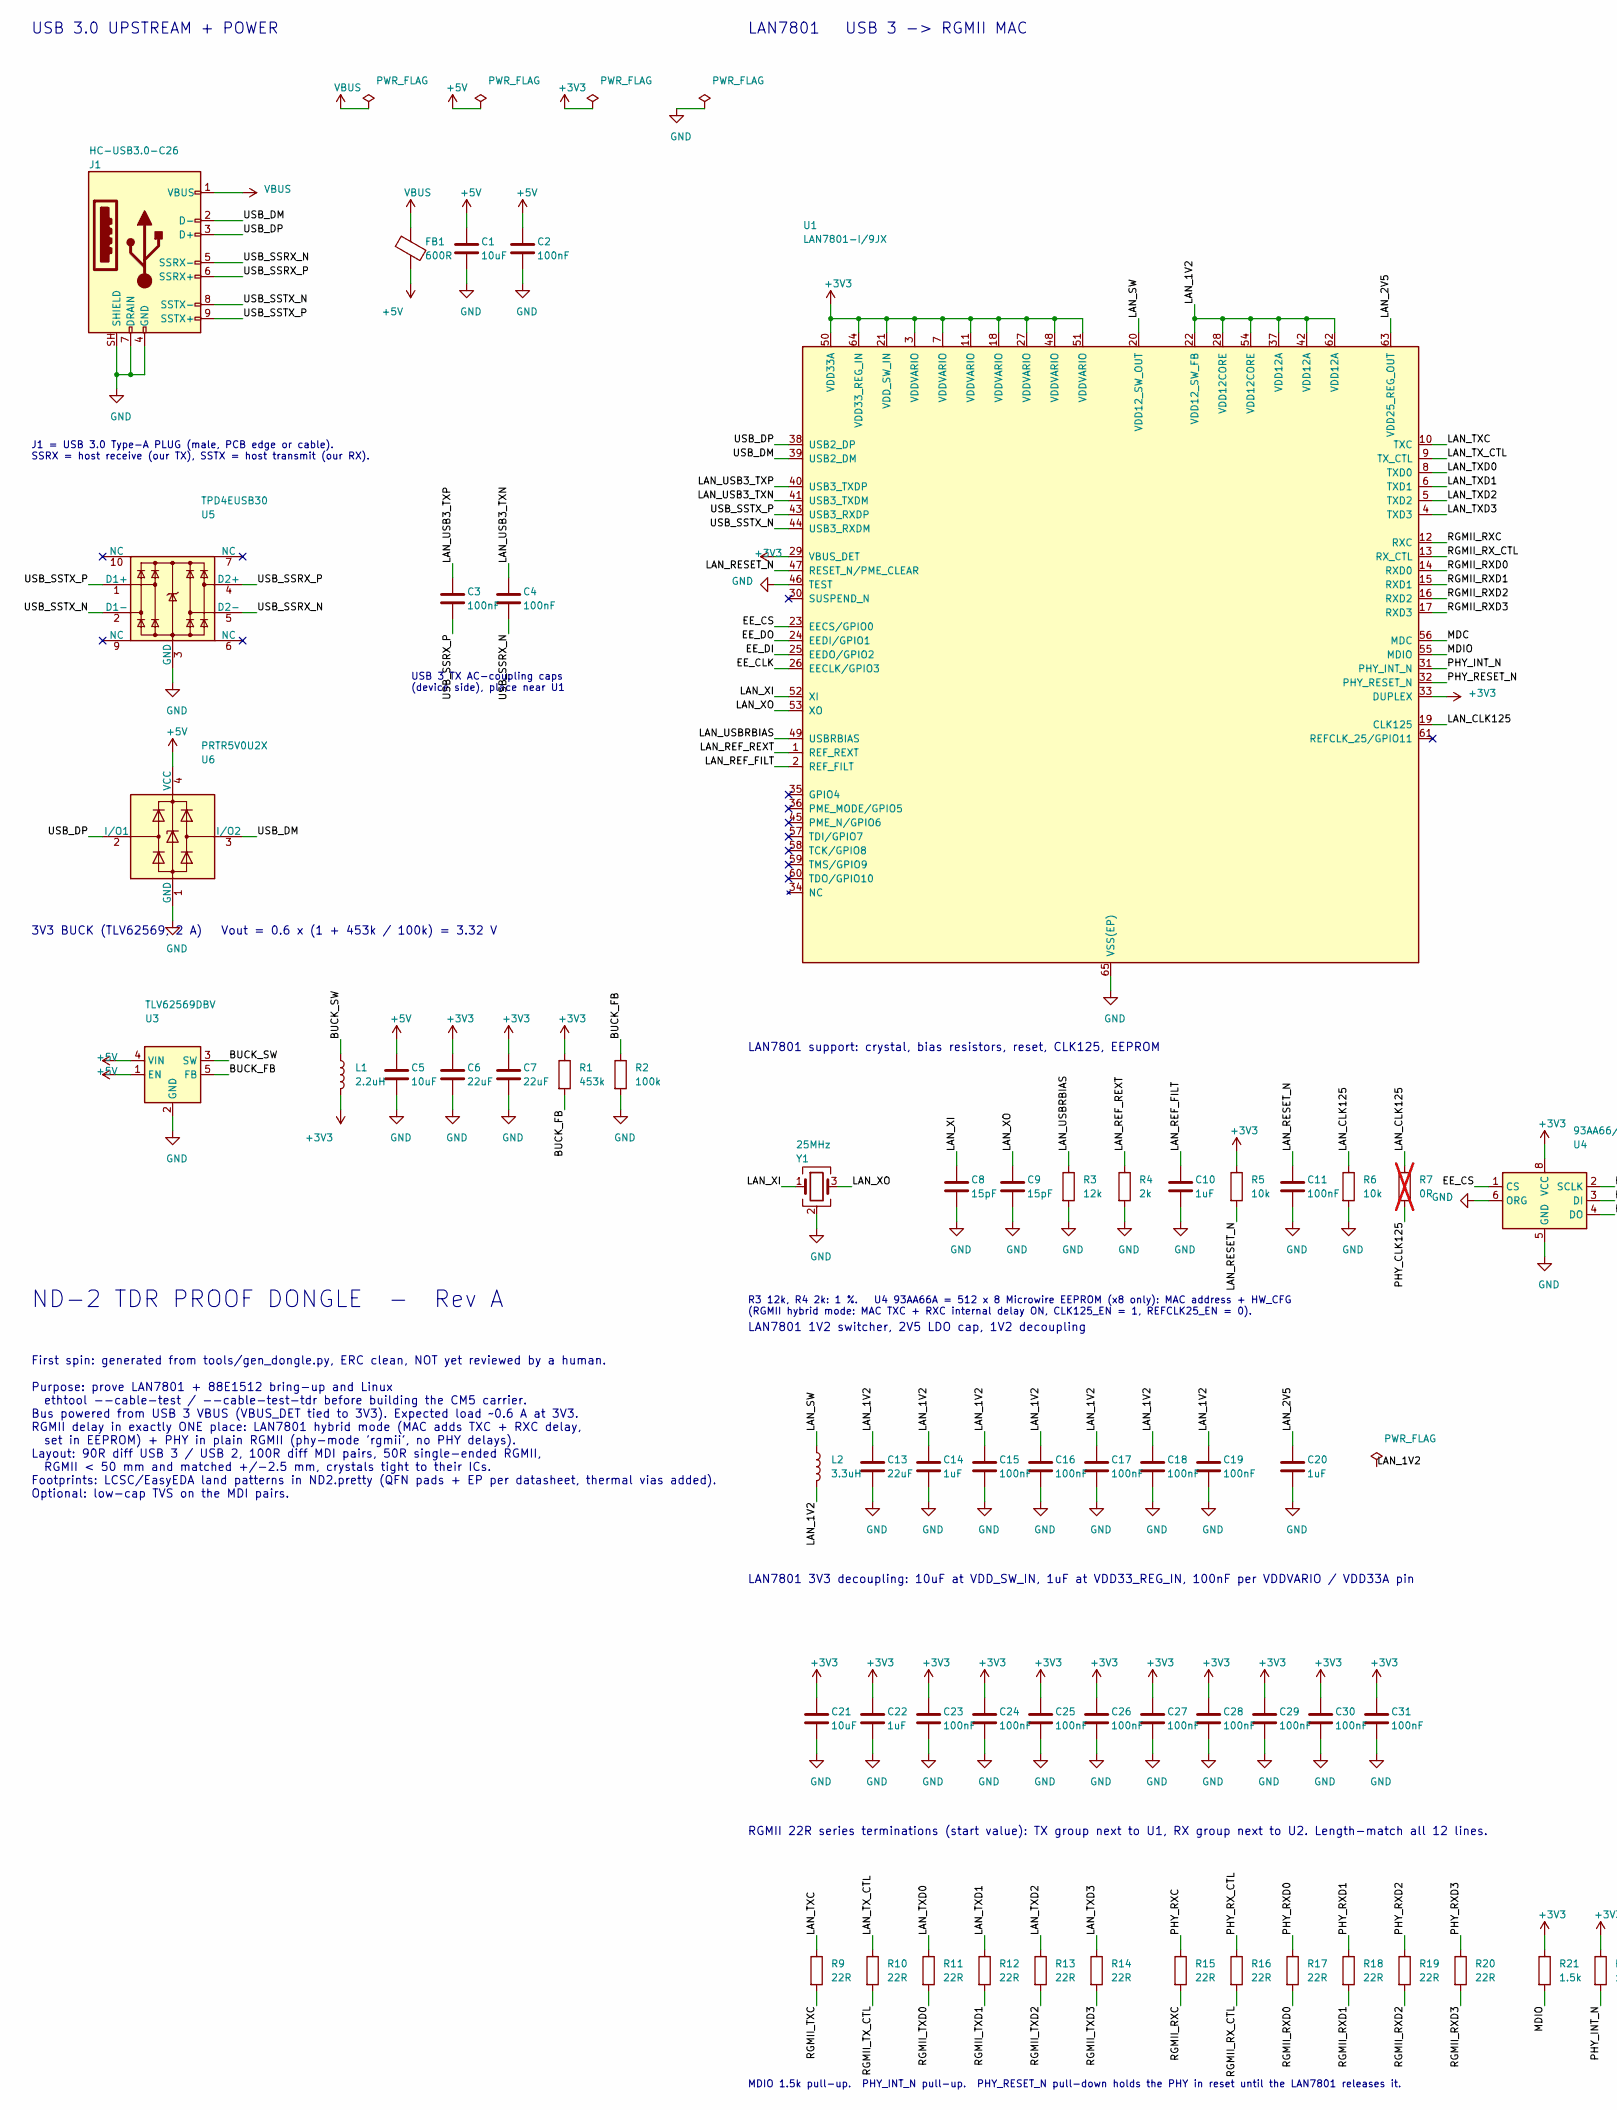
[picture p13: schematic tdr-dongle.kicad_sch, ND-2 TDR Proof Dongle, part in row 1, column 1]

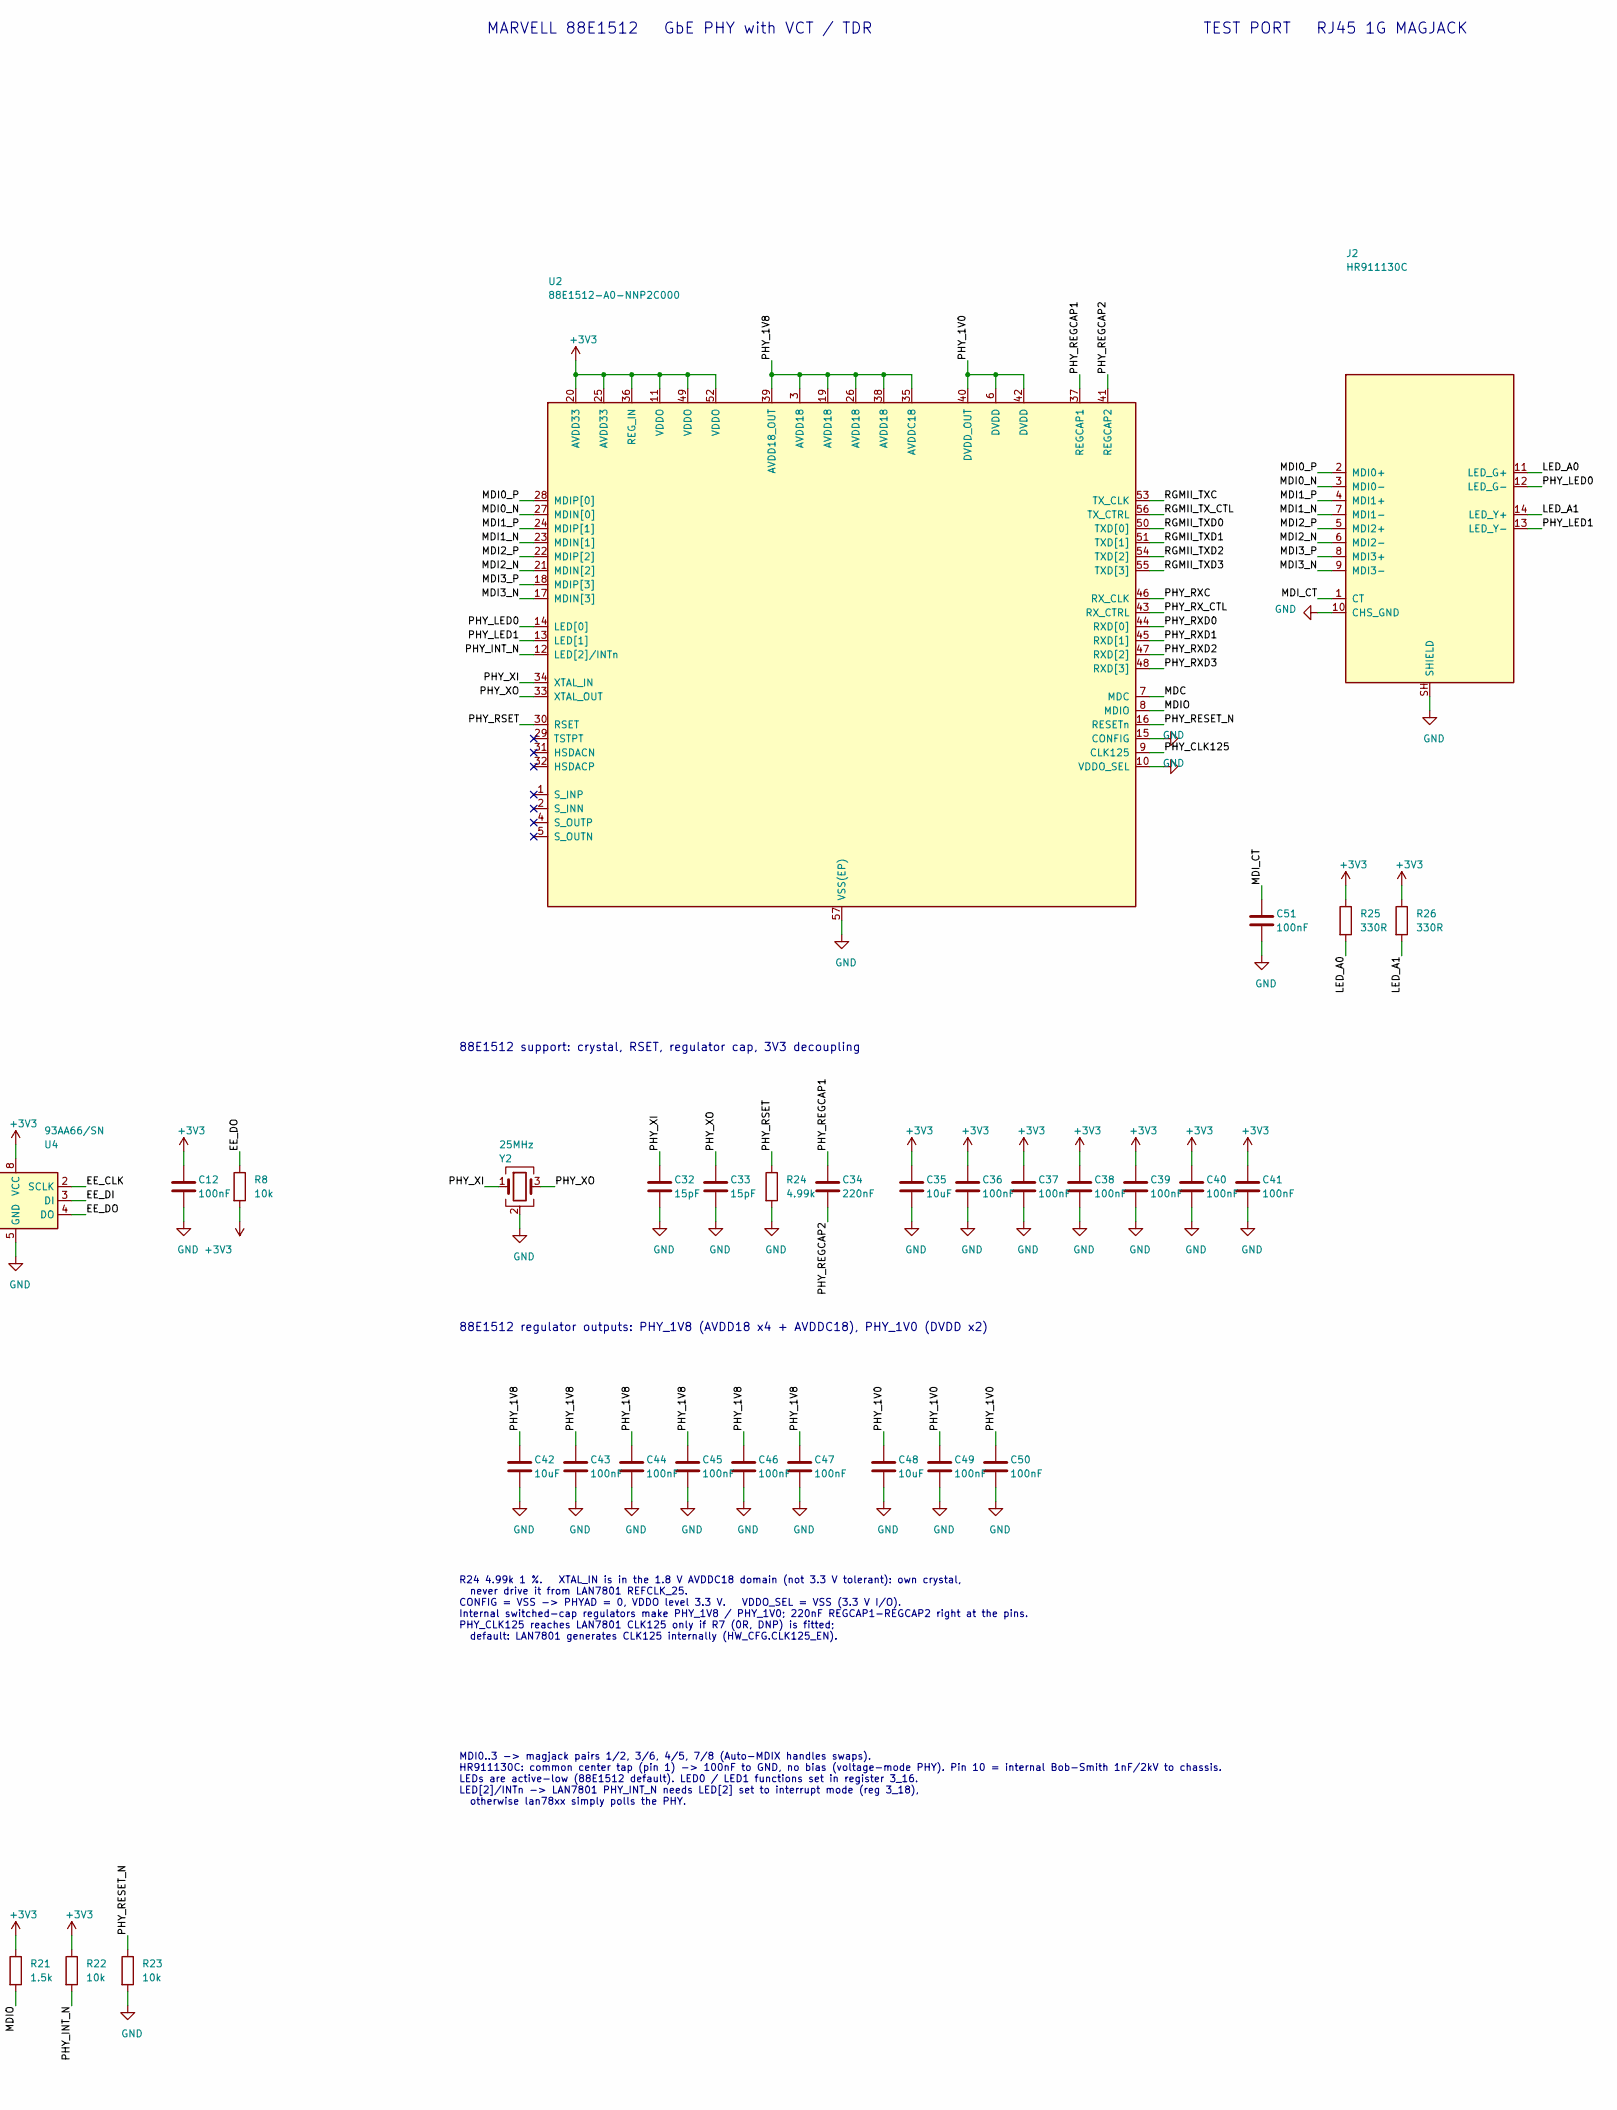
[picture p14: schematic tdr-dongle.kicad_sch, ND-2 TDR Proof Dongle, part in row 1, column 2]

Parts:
C1, C5, C21, C35, C42, C48: 10uF; C_0805_2012Metric; MPN CL21A106KAYNNNE; LCSC C15850
C2, C3, C4, C11, C12, C15, C16, C17, C18, C19, C23, C24, C25, C26, C27, C28, C29, C30, C31, C36, C37, C38, C39, C40, C41, C43, C44, C45, C46, C47, C49, C50, C51: 100nF; C_0402_1005Metric; MPN CL05B104KO5NNNC; LCSC C1525
C6, C7, C13: 22uF; C_0805_2012Metric; MPN CL21A226MAQNNNE; LCSC C45783
C8, C9, C32, C33: 15pF; C_0402_1005Metric; MPN 0402CG150J500NT; LCSC C1548
C10, C14, C20, C22: 1uF; C_0402_1005Metric; MPN CL05A105KA5NQNC; LCSC C52923
C34: 220nF; C_0402_1005Metric; MPN CL05B224KO5NNNC; LCSC C16772
FB1: 600R; L_0805_2012Metric; MPN MPZ2012S601AT000; LCSC C21519
J1: HC-USB3.0-C26; USB3_A_Plug_HongCheng_HC-USB3.0-C26; MPN HC-USB3.0-C26; LCSC C7501854
J2: HR911130C; RJ45_HanRun_HR911130C_Horizontal; MPN HR911130C; LCSC C50933
L1: 2.2uH; L_4.0x4.0mm_SMNR4020; MPN SMNR4020-2.2UH; LCSC C135262
L2: 3.3uH; L_3.0x3.0mm_SMNR3015; MPN SMNR3015-3R3MT; LCSC C135239
R1: 453k; R_0402_1005Metric; MPN 0402WGF4533TCE; LCSC C27009
R2: 100k; R_0402_1005Metric; MPN 0402WGF1003TCE; LCSC C25741
R3: 12k; R_0402_1005Metric; MPN 0402WGF1202TCE; LCSC C25752
R4: 2k; R_0402_1005Metric; MPN 0402WGF2001TCE; LCSC C4109
R5, R6, R8, R22, R23: 10k; R_0402_1005Metric; MPN 0402WGF1002TCE; LCSC C25744
R7: 0R; R_0402_1005Metric; MPN 0402WGF0000TCE; LCSC C17168; not fitted
R9, R10, R11, R12, R13, R14, R15, R16, R17, R18, R19, R20: 22R; R_0402_1005Metric; MPN 0402WGF220JTCE; LCSC C25092
R21: 1.5k; R_0402_1005Metric; MPN 0402WGF1501TCE; LCSC C25867
R24: 4.99k; R_0402_1005Metric; MPN 0402WGF4991TCE; LCSC C25903
R25, R26: 330R; R_0402_1005Metric; MPN 0402WGF3300TCE; LCSC C25104
U1: LAN7801-I/9JX; LAN7801_QFN-64-1EP_9x9mm_P0.5mm_EP6.1mm; MPN LAN7801-I/9JX; LCSC C633491
U2: 88E1512-A0-NNP2C000; 88E1512_QFN-56-1EP_8x8mm_P0.5mm_EP4.4mm; MPN 88E1512-A0-NNP2C000; LCSC C845579
U3: TLV62569DBV; SOT-23-5; MPN TLV62569DBVR; LCSC C141836
U4: 93AA66/SN; SOIC-8_3.9x4.9mm_P1.27mm; MPN 93AA66/SN; LCSC C615340
U5: TPD4EUSB30; USON-10_2.5x1.0mm_P0.5mm; MPN TPD4EUSB30DQAR; LCSC C90627
U6: PRTR5V0U2X; SOT-143; MPN PRTR5V0U2X,215; LCSC C12333
Y1, Y2: 25MHz; Crystal_SMD_3225-4Pin_3.2x2.5mm; MPN X322525MOB4SI; LCSC C9006

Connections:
+3V3: C6.1, C7.1, C12.1, C21.1, C22.1, C23.1, C24.1, C25.1, C26.1, C27.1, C28.1, C29.1, C30.1, C31.1, C35.1, C36.1, C37.1, C38.1, C39.1, C40.1, C41.1, L1.2, R1.1, R5.1, R8.2, R21.1, R22.1, R25.1, R26.1, U1.3 (VDDVARIO), U1.7 (VDDVARIO), U1.11 (VDDVARIO), U1.18 (VDDVARIO), U1.21 (VDD_SW_IN), U1.27 (VDDVARIO), U1.29 (VBUS_DET), U1.33 (DUPLEX), U1.48 (VDDVARIO), U1.50 (VDD33A), U1.51 (VDDVARIO), U1.64 (VDD33_REG_IN), U2.11 (VDDO), U2.20 (AVDD33), U2.25 (AVDD33), U2.36 (REG_IN), U2.49 (VDDO), U2.52 (VDDO), U4.8 (VCC)
+5V: C1.1, C2.1, C5.1, FB1.2, U3.1 (EN), U3.4 (VIN), U6.4 (VCC)
/BUCK_FB: R1.2, R2.1, U3.5 (FB)
/BUCK_SW: L1.1, U3.3 (SW)
/EE_CLK: U1.26 (EECLK/GPIO3), U4.2 (SCLK)
/EE_CS: U1.23 (EECS/GPIO0), U4.1 (CS)
/EE_DI: U1.25 (EEDO/GPIO2), U4.3 (DI)
/EE_DO: R8.1, U1.24 (EEDI/GPIO1), U4.4 (DO)
/LAN_1V2: C13.1, C14.1, C15.1, C16.1, C17.1, C18.1, C19.1, L2.2, U1.22 (VDD12_SW_FB), U1.28 (VDD12CORE), U1.37 (VDD12A), U1.42 (VDD12A), U1.54 (VDD12CORE), U1.62 (VDD12A)
/LAN_2V5: C20.1, U1.63 (VDD25_REG_OUT)
/LAN_CLK125: R6.1, R7.1, U1.19 (CLK125)
/LAN_REF_FILT: C10.1, U1.2 (REF_FILT)
/LAN_REF_REXT: R4.1, U1.1 (REF_REXT)
/LAN_RESET_N: C11.1, R5.2, U1.47 (RESET_N/PME_CLEAR)
/LAN_SW: L2.1, U1.20 (VDD12_SW_OUT)
/LAN_TXC: R9.1, U1.10 (TXC)
/LAN_TXD0: R11.1, U1.8 (TXD0)
/LAN_TXD1: R12.1, U1.6 (TXD1)
/LAN_TXD2: R13.1, U1.5 (TXD2)
/LAN_TXD3: R14.1, U1.4 (TXD3)
/LAN_TX_CTL: R10.1, U1.9 (TX_CTL)
/LAN_USB3_TXN: C4.1, U1.41 (USB3_TXDM)
/LAN_USB3_TXP: C3.1, U1.40 (USB3_TXDP)
/LAN_USBRBIAS: R3.1, U1.49 (USBRBIAS)
/LAN_XI: C8.1, U1.52 (XI), Y1.1
/LAN_XO: C9.1, U1.53 (XO), Y1.3
/LED_A0: J2.11 (LED_G+), R25.2
/LED_A1: J2.14 (LED_Y+), R26.2
/MDC: U1.56 (MDC), U2.7 (MDC)
/MDI0_N: J2.3 (MDI0-), U2.27 (MDIN[0])
/MDI0_P: J2.2 (MDI0+), U2.28 (MDIP[0])
/MDI1_N: J2.7 (MDI1-), U2.23 (MDIN[1])
/MDI1_P: J2.4 (MDI1+), U2.24 (MDIP[1])
/MDI2_N: J2.6 (MDI2-), U2.21 (MDIN[2])
/MDI2_P: J2.5 (MDI2+), U2.22 (MDIP[2])
/MDI3_N: J2.9 (MDI3-), U2.17 (MDIN[3])
/MDI3_P: J2.8 (MDI3+), U2.18 (MDIP[3])
/MDIO: R21.2, U1.55 (MDIO), U2.8 (MDIO)
/MDI_CT: C51.1, J2.1 (CT)
/PHY_1V0: C48.1, C49.1, C50.1, U2.6 (DVDD), U2.40 (DVDD_OUT), U2.42 (DVDD)
/PHY_1V8: C42.1, C43.1, C44.1, C45.1, C46.1, C47.1, U2.3 (AVDD18), U2.19 (AVDD18), U2.26 (AVDD18), U2.35 (AVDDC18), U2.38 (AVDD18), U2.39 (AVDD18_OUT)
/PHY_CLK125: R7.2, U2.9 (CLK125)
/PHY_INT_N: R22.2, U1.31 (PHY_INT_N), U2.12 (LED[2]/INTn)
/PHY_LED0: J2.12 (LED_G-), U2.14 (LED[0])
/PHY_LED1: J2.13 (LED_Y-), U2.13 (LED[1])
/PHY_REGCAP1: C34.1, U2.37 (REGCAP1)
/PHY_REGCAP2: C34.2, U2.41 (REGCAP2)
/PHY_RESET_N: R23.1, U1.32 (PHY_RESET_N), U2.16 (RESETn)
/PHY_RSET: R24.1, U2.30 (RSET)
/PHY_RXC: R15.1, U2.46 (RX_CLK)
/PHY_RXD0: R17.1, U2.44 (RXD[0])
/PHY_RXD1: R18.1, U2.45 (RXD[1])
/PHY_RXD2: R19.1, U2.47 (RXD[2])
/PHY_RXD3: R20.1, U2.48 (RXD[3])
/PHY_RX_CTL: R16.1, U2.43 (RX_CTRL)
/PHY_XI: C32.1, U2.34 (XTAL_IN), Y2.1
/PHY_XO: C33.1, U2.33 (XTAL_OUT), Y2.3
/RGMII_RXC: R15.2, U1.12 (RXC)
/RGMII_RXD0: R17.2, U1.14 (RXD0)
/RGMII_RXD1: R18.2, U1.15 (RXD1)
/RGMII_RXD2: R19.2, U1.16 (RXD2)
/RGMII_RXD3: R20.2, U1.17 (RXD3)
/RGMII_RX_CTL: R16.2, U1.13 (RX_CTL)
/RGMII_TXC: R9.2, U2.53 (TX_CLK)
/RGMII_TXD0: R11.2, U2.50 (TXD[0])
/RGMII_TXD1: R12.2, U2.51 (TXD[1])
/RGMII_TXD2: R13.2, U2.54 (TXD[2])
/RGMII_TXD3: R14.2, U2.55 (TXD[3])
/RGMII_TX_CTL: R10.2, U2.56 (TX_CTRL)
/USB_DM: J1.2 (D-), U1.39 (USB2_DM), U6.3 (I/O2)
/USB_DP: J1.3 (D+), U1.38 (USB2_DP), U6.2 (I/O1)
/USB_SSRX_N: C4.2, J1.5 (SSRX-), U5.5 (D2-)
/USB_SSRX_P: C3.2, J1.6 (SSRX+), U5.4 (D2+)
/USB_SSTX_N: J1.8 (SSTX-), U1.44 (USB3_RXDM), U5.2 (D1-)
/USB_SSTX_P: J1.9 (SSTX+), U1.43 (USB3_RXDP), U5.1 (D1+)
GND: C1.2, C2.2, C5.2, C6.2, C7.2, C8.2, C9.2, C10.2, C11.2, C12.2, C13.2, C14.2, C15.2, C16.2, C17.2, C18.2, C19.2, C20.2, C21.2, C22.2, C23.2, C24.2, C25.2, C26.2, C27.2, C28.2, C29.2, C30.2, C31.2, C32.2, C33.2, C35.2, C36.2, C37.2, C38.2, C39.2, C40.2, C41.2, C42.2, C43.2, C44.2, C45.2, C46.2, C47.2, C48.2, C49.2, C50.2, C51.2, J1.4 (GND), J1.7 (DRAIN), J1.SH (SHIELD), J2.10 (CHS_GND), J2.SH (SHIELD), R2.2, R3.2, R4.2, R6.2, R23.2, R24.2, U1.46 (TEST), U1.65 (VSS(EP)), U2.10 (VDDO_SEL), U2.15 (CONFIG), U2.57 (VSS(EP)), U3.2 (GND), U4.5 (GND), U4.6 (ORG), U5.3 (GND), U5.8 (GND), U6.1 (GND), Y1.2 (G), Y1.4 (G), Y2.2 (G), Y2.4 (G)
VBUS: FB1.1, J1.1 (VBUS)

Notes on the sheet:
USB 3.0 UPSTREAM + POWER
J1 = USB 3.0 Type-A PLUG (male, PCB edge or cable). SSRX = host receive (our TX), SSTX = host transmit (our RX).
USB 3 TX AC-coupling caps (device side), place near U1
3V3 BUCK (TLV62569, 2 A) Vout = 0.6 x (1 + 453k / 100k) = 3.32 V
LAN7801 USB 3 -> RGMII MAC
LAN7801 support: crystal, bias resistors, reset, CLK125, EEPROM
R3 12k, R4 2k: 1 %. U4 93AA66A = 512 x 8 Microwire EEPROM (x8 only): MAC address + HW_CFG (RGMII hybrid mode: MAC TXC + RXC internal delay ON, CLK125_EN = 1, REFCLK25_EN = 0).
LAN7801 1V2 switcher, 2V5 LDO cap, 1V2 decoupling
LAN7801 3V3 decoupling: 10uF at VDD_SW_IN, 1uF at VDD33_REG_IN, 100nF per VDDVARIO / VDD33A pin
RGMII 22R series terminations (start value): TX group next to U1, RX group next to U2. Length-match all 12 lines.
MDIO 1.5k pull-up. PHY_INT_N pull-up. PHY_RESET_N pull-down holds the PHY in reset until the LAN7801 releases it.
MARVELL 88E1512 GbE PHY with VCT / TDR
88E1512 support: crystal, RSET, regulator cap, 3V3 decoupling
88E1512 regulator outputs: PHY_1V8 (AVDD18 x4 + AVDDC18), PHY_1V0 (DVDD x2)
R24 4.99k 1 %. XTAL_IN is in the 1.8 V AVDDC18 domain (not 3.3 V tolerant): own crystal, never drive it from LAN7801 REFCLK_25. CONFIG = VSS -> PHYAD = 0, VDDO level 3.3 V. VDDO_SEL = VSS (3.3 V I/O). Internal switched-cap regulators make PHY_1V8 / PHY_1V0; 220nF REGCAP1-REGCAP2 right at the pins. 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
MDI0..3 -> magjack pairs 1/2, 3/6, 4/5, 7/8 (Auto-MDIX handles swaps). HR911130C: common center tap (pin 1) -> 100nF to GND, no bias (voltage-mode PHY). Pin 10 = internal Bob-Smith 1nF/2kV to chassis. LEDs are active-low (88E1512 default). LED0 / LED1 functions set in register 3_16. LED[2]/INTn -> 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
TEST PORT RJ45 1G MAGJACK
ND-2 TDR PROOF DONGLE - Rev A
First spin: generated from tools/gen_dongle.py, ERC clean, NOT yet reviewed by a human. Purpose: prove LAN7801 + 88E1512 bring-up and Linux ethtool --cable-test / --cable-test-tdr before building the CM5 carrier. Bus powered from USB 3 VBUS (VBUS_DET tied to 3V3). Expected load ~0.6 A at 3V3. RGMII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

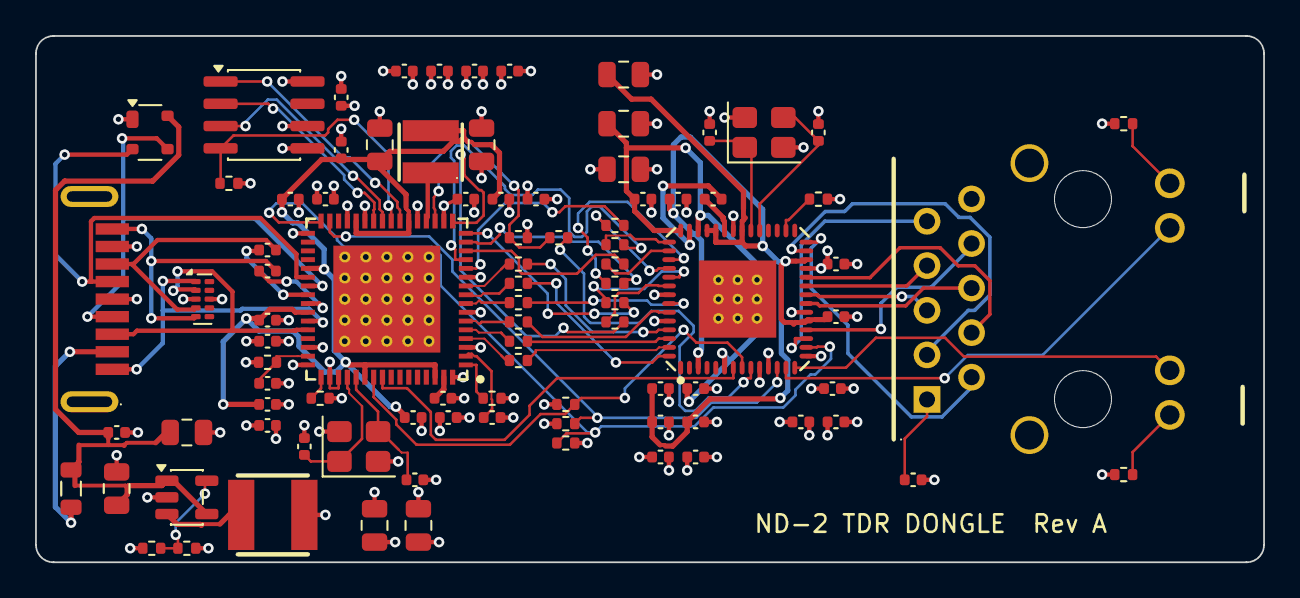
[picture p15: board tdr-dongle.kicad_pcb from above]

Board: 4 copper layers, 70.0 x 30.0 mm, 90 parts (0 on the bottom side), 77 nets.

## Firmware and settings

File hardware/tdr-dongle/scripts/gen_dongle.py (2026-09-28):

#!/usr/bin/env python3
"""Generate the ND-2 TDR proof dongle schematic (LAN7801 + Marvell 88E1512) for KiCad 10.

Label-based schematic: every pin gets a short stub wire ending in a net label or power
symbol, so connectivity is defined purely by net names (easy to review, easy to edit).
Re-run to regenerate; edits made by hand in KiCad will be overwritten.
Usage: python3 gen_dongle.py <kicad_symbol_lib_dir> <output_project_dir>
"""
import re, uuid, math, os, sys

LIBDIR = sys.argv[1] if len(sys.argv) > 1 else '_libcache'
PROJ = sys.argv[2] if len(sys.argv) > 2 else '.'
NAME = 'tdr-dongle'
ROOT_UUID = str(uuid.uuid5(uuid.NAMESPACE_DNS, 'nd2-tdr-dongle-root'))
_uc = [0]


def U():
    _uc[0] += 1
    return str(uuid.uuid5(uuid.NAMESPACE_DNS, 'nd2-tdr-%d' % _uc[0]))


def fmt(v):
    v = round(v, 4)
    s = ('%.4f' % v).rstrip('0').rstrip('.')
    return '0' if s in ('-0', '') else s


# ---------------------------------------------------------------- s-expr helpers
def _balanced(s, i):
    d = 0; j = i; inq = False
    while True:
        c = s[j]
        if inq:
            if c == '\\':
                j += 2; continue
            if c == '"':
                inq = False
        else:
            if c == '"':
                inq = True
            elif c == '(':
                d += 1
            elif c == ')':
                d -= 1
                if d == 0:
                    return j + 1
        j += 1


def extract(s, name):
    i = s.find('(symbol "%s"' % name)
    assert i >= 0, name
    return s[i:_balanced(s, i)]


def blocks(s, head):
    out = []; k = 0
    while True:
        i = s.find(head, k)
        if i < 0:
            return out
        j = _balanced(s, i)
        out.append(s[i:j]); k = j


def parse_pins(symtext):
    pins = []
    for b in blocks(symtext, '(pin '):
        m = re.match(r'\(pin (\w+) (\w+)\s*\(at ([-\d.]+) ([-\d.]+) ([-\d.]+)\)', b)
        num = re.search(r'\(number "([^"]*)"', b).group(1)
        nm = re.search(r'\(name "([^"]*)"', b).group(1)
        pins.append(dict(num=num, name=nm, type=m.group(1), x=float(m.group(3)),
                         y=float(m.group(4)), a=float(m.group(5))))
    return pins


LIBS = {}


def libsym(lib, name):
    key = '%s:%s' % (lib, name)
    if key not in LIBS:
        s = open(os.path.join(LIBDIR, lib + '.kicad_sym'), encoding='utf-8').read()
        t = extract(s, name)
        assert '(extends' not in t, key
        LIBS[key] = dict(text=t.replace('(symbol "%s"' % name, '(symbol "%s"' % key, 1), pins=parse_pins(t))
    return LIBS[key]


# ---------------------------------------------------------------- custom IC symbols
def gen_ic(name, ref, value, desc, datasheet, left, right, top, bottom, min_w=40.64):
    """left/right: 2.54 pitch lists of (num,name,type) or None (gap); top/bottom at 5.08 pitch."""
    def maxlen(lst):
        return max([len(p[1]) for p in lst if p] + [1])
    n_lr = max(len(left), len(right))
    H = math.ceil((22.86 + (n_lr - 1) * 2.54 + 5.08) / 5.08) * 5.08
    W = max(min_w, 10.16 + (max(len(top), len(bottom)) - 1) * 5.08, (maxlen(left) + maxlen(right)) * 1.27 + 12.7)
    W = math.ceil(W / 5.08) * 5.08
    x0, y0 = -W / 2, H / 2
    pins = []
    for i, p in enumerate(left):
        if p: pins.append((p, x0 - 2.54, y0 - 17.78 - i * 2.54, 0))
    for i, p in enumerate(right):
        if p: pins.append((p, -x0 + 2.54, y0 - 17.78 - i * 2.54, 180))
    tx0 = math.floor((-((len(top) - 1) * 5.08) / 2) / 2.54) * 2.54
    for i, p in enumerate(top):
        if p: pins.append((p, tx0 + i * 5.08, y0 + 2.54, 270))
    bx0 = math.floor((-((len(bottom) - 1) * 5.08) / 2) / 2.54) * 2.54
    for i, p in enumerate(bottom):
        if p: pins.append((p, bx0 + i * 5.08, -y0 - 2.54, 90))
    F = '(effects (font (size 1.27 1.27)))'
    pt = ['(pin %s line (at %s %s %s) (length 2.54) (name "%s" %s) (number "%s" %s))'
          % (typ, fmt(x), fmt(y), fmt(a), nm, F, num, F) for (num, nm, typ), x, y, a in pins]
    body = ('(symbol "{N}" (pin_names (offset 1.016)) (exclude_from_sim no) (in_bom yes) (on_board yes)'
            ' (property "Reference" "{R}" (at {x0} {ry} 0) (effects (font (size 1.27 1.27)) (justify left)))'
            ' (property "Value" "{V}" (at {x0} {vy} 0) (effects (font (size 1.27 1.27)) (justify left)))'
            ' (property "Footprint" "" (at 0 0 0) (effects (font (size 1.27 1.27)) (hide yes)))'
            ' (property "Datasheet" "{D}" (at 0 0 0) (effects (font (size 1.27 1.27)) (hide yes)))'
            ' (property "Description" "{DS}" (at 0 0 0) (effects (font (size 1.27 1.27)) (hide yes)))'
            ' (symbol "{N}_0_1" (rectangle (start {x0} {y0}) (end {x1} {y1}) (stroke (width 0.254) (type default)) (fill (type background))))'
            ' (symbol "{N}_1_1" {PINS}) (embedded_fonts no))').format(
        N=name, R=ref, V=value, D=datasheet, DS=desc, ry=fmt(-y0 - 7.62), vy=fmt(-y0 - 10.16),
        x0=fmt(x0), y0=fmt(y0), x1=fmt(-x0), y1=fmt(-y0), PINS=' '.join(pt))
    key = 'ND2:' + name
    LIBS[key] = dict(text=body.replace('(symbol "%s"' % name, '(symbol "%s"' % key, 1), pins=parse_pins(body), W=W, H=H)
    return body
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

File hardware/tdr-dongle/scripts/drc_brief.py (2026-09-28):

import json, collections, subprocess, sys, os
P = r"C:\path\to\ND2\tdr-dongle"
pcb = sys.argv[1] if len(sys.argv) > 1 and sys.argv[1] else P + r"\tdr-dongle.kicad_pcb"
cli = r"C:\Program Files\KiCad\10.0\bin\kicad-cli.exe"
out = P + r"\drc.json"
if os.path.exists(out): os.remove(out)
r = subprocess.run([cli, "pcb", "drc", "--format", "json", "--severity-all", "--schematic-parity", "--refill-zones", "-o", out, pcb], capture_output=True, text=True)
d = json.load(open(out))
v = d["violations"]
print(collections.Counter((x["type"], x["severity"]) for x in v), "unconnected", len(d["unconnected_items"]), "parity", len(d["schematic_parity"]))
seen = collections.Counter()
for x in v:
    seen[x["type"]] += 1
    if seen[x["type"]] > 6: continue
    print(x["type"], "|", x["description"][:80], "|", [(i["description"][:50], round(i["pos"]["x"] - 100, 2), round(i["pos"]["y"] - 100, 2)) for i in x["items"]])
for x in d["unconnected_items"]:
    print("UNCONN", [(i["description"][:50], round(i["pos"]["x"] - 100, 2), round(i["pos"]["y"] - 100, 2)) for i in x["items"]])
